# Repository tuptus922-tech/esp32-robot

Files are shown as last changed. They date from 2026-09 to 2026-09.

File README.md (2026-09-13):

# 🤖 ESP32 Robot Desk Pet — Kompletny Przewodnik

Interaktywny miniaturowy robot biurkowy (**Desk Companion Pet**) oparty na mikrokontrolerze **ESP32**, wyświetlaczu OLED 0.96", akcelerometrze/żyroskopie **MPU-6050**, podwójnym pojemnościowym czujniku głaskania oraz pasywnym buzzerze piezo.

Dzięki **modułowej architekturze Core-and-Armor** całą elektronikę montujesz i podłączasz **tylko jeden raz** w centralnym stelażu, a wygląd zewnętrzny robota możesz zmieniać w sekundę, nasuwając wybraną obudowę (**Cyber-Titan Apex**, **Mecha-Kawaii**, **Retro CRT** lub **Steam-Titan Nautilus**) bez rozkręcania śrub i bez dotykania kabli!

---

## ⚡ Spis Treści
1. [KROK 1: Flashowanie ESP32 (Wgrywanie programu)](#-krok-1-flashowanie-esp32-wgrywanie-programu)
2. [KROK 2: Druk 3D — Dokładna lista plików STL (4 style)](#-krok-2-druk-3d--dokładna-lista-plików-stl)
3. [KROK 3: Schemat połączeń przewodów (Hardware Pinout)](#-krok-3-schemat-połączeń-przewodów-hardware-pinout)
4. [KROK 4: Montaż elektroniki w stelażu (Złóż raz i zapomnij!)](#-krok-4-montaż-elektroniki-w-stelażu-złóż-raz-i-zapomnij)
5. [KROK 5: Błyskawiczna wymiana obudów (Quick-Swap Slide-On)](#-krok-5-błyskawiczna-wymiana-obudów-quick-swap-slide-on)
6. [✨ Funkcje, animacje i sterowanie](#-funkcje-animacje-i-sterowanie)
7. [📦 Lista zakupowa części (BOM)](#-lista-zakupowa-części-bom)

---

## ⚡ KROK 1: Flashowanie ESP32 (Wgrywanie programu)

Kod robota znajduje się w pliku [`src/main.cpp`](src/main.cpp), a konfiguracja projektu, parametry mikrokontrolera i biblioteki są zdefiniowane w [`platformio.ini`](platformio.ini).

### Wymagania:
* Płytka **ESP32 DevKit V1** (30-pin, polecane z gniazdem USB-C lub microUSB).
* Kabel USB **do transmisji danych** (nie tylko do ładowania!).
* Komputer z Windows, macOS lub Linux.

---

### Metoda A: Przez VS Code + PlatformIO IDE (Najprostsza — Zalecana)

1. **Pobierz i zainstaluj edytor [VS Code (Visual Studio Code)](https://code.visualstudio.com/)**.
2. W VS Code przejdź do zakładki rozszerzeń (`Ctrl + Shift + X`), wyszukaj **PlatformIO IDE** i kliknij **Install**.
3. Kliknij `File -> Open Folder...` i wskaż sklonowany folder projektu:
   ```bash
   esp32-robot
   ```
4. Podłącz płytkę ESP32 kablem USB do portu komputera.
5. Na dolnym niebieskim pasku VS Code pojawią się ikonki PlatformIO:
   * **`✓` (Build)**: kompilacja programu.
   * **`→` (Upload)**: automatyczna kompilacja i wgranie programu do pamięci ESP32!
   * **`🔌` (Serial Monitor)**: podgląd logów diagnostycznych (115200 baud).
6. Kliknij **`→` (Upload)**. PlatformIO samoczynnie pobierze wymagane biblioteki (Adafruit SSD1306, GFX, MPU6050, BusIO), skompiluje kod i wgra go na Twoją płytkę.
7. Po wgraniu robot wyda powitalny dźwięk i otworzy animowane oczy na ekranie!

---

### Metoda B: Przez Terminal (CLI)

Jeśli wolisz terminal, wystarczy wpisać:

```bash
# 1. Przejdź do katalogu projektu
cd esp32-robot

# 2. Skompiluj i wgraj program na podłączone ESP32
pio run -t upload

# 3. Otwórz monitor portu szeregowego
pio device monitor -b 115200
```
*(Jeśli komenda `pio` nie jest w ścieżce PATH, użyj pełnej ścieżki: `~/.platformio/penv/bin/pio run -t upload`)*

---

### ❓ Rozwiązywanie problemów z wgrywaniem:

* **Błąd `Connecting........_____.....`**:  
  Niektóre płytki ESP32 wymagają ręcznego wejścia w tryb bootloadera. Gdy na ekranie pojawi się napis `Connecting...`, **naciśnij i przytrzymaj przez 2 sekundy przycisk BOOT** na płytce ESP32, po czym puść.
* **Komputer nie widzi portu COM / `/dev/ttyUSB0`**:  
  Zainstaluj uniwersalne sterowniki układu USB-UART dla ESP32: **CP2102** (Silicon Labs) lub **CH340**.
* **Chcesz przetestować kod bez fizycznej płytki?**  
  Projekt zawiera plik [`diagram.json`](diagram.json) — możesz uruchomić pełną symulację robota w wirtualnym środowisku **Wokwi** w przeglądarce!

---

## 🖨️ KROK 2: Druk 3D — Dokładna lista plików STL

Projekt wykorzystuje modułowy system **Core-and-Armor**:
1. **Drukujesz ZAWSZE 1x Stelaż Centralny (Universal Core Chassis v2.0 - Pro Precision Edition)** — to w nim na stałe mieszka cała elektronika w dedykowanych gniazdach pod dokładne wymiary fabryczne podzespołów.
2. **Wybierasz 1 z 4 obudów zewnętrznych (Głowa + Klawisze)** — nasuwasz ją od góry na stelaż (**Quick-Swap Slide-On**)!

---

### 🧩 CZĘŚĆ 1: Centralny Stelaż (Drukujesz ZAWSZE, 1 raz dla każdego robota)

| Plik STL | Ilość | Ścieżka do pliku | Dedykowane gniazda i wymiary |
| :--- | :---: | :--- | :--- |
| **`core_chassis.stl`** | **1 szt.** | [`cad_models/stl_print/core_chassis.stl`](cad_models/stl_print/core_chassis.stl) | **Stelaż v2.0 z dedykowanymi gniazdami:**<br>• **ESP32 DevKit V1**: gniazdo 51.8x28.7mm z 2 głębokimi kanałami na 2x15 pinów goldpin + tunel kablowy<br>• **OLED 0.96" I2C**: kieszeń 27.4x27.4mm, standardowe otwory M2 w rozstawie **23.5x23.5mm**, kąt 80° z kratownicą<br>• **MPU-6050 (GY-521)**: kieszeń 21.2x16.0mm, 2x otwory M2.5 (rozstaw 15.2mm) i okno na piny<br>• **Buzzer 12mm**: kubek akustyczny fi 12.4x9.5mm z 2 otworami na piny (rozstaw 7.6mm)<br>• **3x Switche 6x6mm**: 3 kieszenie 6.5x6.5x4.2mm z przepustami na nóżki |

---

### 🎭 CZĘŚĆ 2: Wybierz 1 z 3 Obudów Zewnętrznych (Nasuwasz na stelaż)

#### 🛡️ Opcja A: Cyber-Titan Apex (Ciężki Mech Bojowy 72mm z wyrzutniami, rogami i dyszami)
*Klimat: Armored Core / Gundam Heavy Assault. Agresywna sylwetka V-Taper, potężne naramienniki 72mm z wyrzutniami rakiet, 68mm rogi bojowe V-Fin, kły mandibles i podwójne dysze dopalaczy.*

| Plik STL | Ilość | Ścieżka do pliku | Zalecany kolor filamentu |
| :--- | :---: | :--- | :--- |
| **`dreadnought_glowa.stl`** | **1 szt.** | [`cad_models/stl_print/dreadnought/dreadnought_glowa.stl`](cad_models/stl_print/dreadnought/dreadnought_glowa.stl) | Matowy grafit / Carbon Black |
| **`dreadnought_przycisk_romb.stl`** | **1 szt.** | [`cad_models/stl_print/dreadnought/dreadnought_przycisk_romb.stl`](cad_models/stl_print/dreadnought/dreadnought_przycisk_romb.stl) | Złoty metalik lub Cyber Pomarańcz |
| **`dreadnought_przycisk_strzalka_l.stl`** | **1 szt.** | [`cad_models/stl_print/dreadnought/dreadnought_przycisk_strzalka_l.stl`](cad_models/stl_print/dreadnought/dreadnought_przycisk_strzalka_l.stl) | Tytanowy szary / Ciemny grafit |
| **`dreadnought_przycisk_strzalka_p.stl`** | **1 szt.** | [`cad_models/stl_print/dreadnought/dreadnought_przycisk_strzalka_p.stl`](cad_models/stl_print/dreadnought/dreadnought_przycisk_strzalka_p.stl) | Tytanowy szary / Ciemny grafit |
| *`dreadnought_podstawa.stl`* | *(opcjonalnie)* | [`cad_models/stl_print/dreadnought/dreadnought_podstawa.stl`](cad_models/stl_print/dreadnought/dreadnought_podstawa.stl) | *Opcjonalna baza ze stopami czołgowymi* |

---

#### 🌸 Opcja B: Cyber-Capsule Mecha-Kawaii (Anime Kotek Neko ze szponterami)
*Klimat: Cyberpunk Anime Companion. Przestrzenny wizjer 3D, kocie uszka, nauszniki Audio-Pod, 4 boczne żebra pancerza ("szpontery"), wąsy i przyciski z serduszkiem oraz łapkami.*

| Plik STL | Ilość | Ścieżka do pliku | Zalecany kolor filamentu |
| :--- | :---: | :--- | :--- |
| **`mecha_kawaii_glowa.stl`** | **1 szt.** | [`cad_models/stl_print/mecha_kawaii/mecha_kawaii_glowa.stl`](cad_models/stl_print/mecha_kawaii/mecha_kawaii_glowa.stl) | Pastel Sakura Pink / Perłowa biel |
| **`mecha_kawaii_przycisk_serce.stl`** | **1 szt.** | [`cad_models/stl_print/mecha_kawaii/mecha_kawaii_przycisk_serce.stl`](cad_models/stl_print/mecha_kawaii/mecha_kawaii_przycisk_serce.stl) | Neon Fuksja / Czerwony |
| **`mecha_kawaii_przycisk_lapka.stl`** | **2 szt.** | [`cad_models/stl_print/mecha_kawaii/mecha_kawaii_przycisk_lapka.stl`](cad_models/stl_print/mecha_kawaii/mecha_kawaii_przycisk_lapka.stl) | Śmietankowa biel |
| *`mecha_kawaii_podstawa.stl`* | *(opcjonalnie)* | [`cad_models/stl_print/mecha_kawaii/mecha_kawaii_podstawa.stl`](cad_models/stl_print/mecha_kawaii/mecha_kawaii_podstawa.stl) | *Opcjonalna baza z przednimi łapkami* |

---

#### 📺 Opcja C: Retro CRT Minimalist (Klasyczny Komputer Biurkowy Vintage)
*Klimat: Macintosh 1984 / Dieter Rams Braun. Minimalistyczna bryła o miękkich krawędziach R4, zlicowane okno ekranu i ergonomiczne kopułki przycisków.*

| Plik STL | Ilość | Ścieżka do pliku | Zalecany kolor filamentu |
| :--- | :---: | :--- | :--- |
| **`obudowa_gora_glowa.stl`** | **1 szt.** | [`cad_models/stl_print/obudowa_gora_glowa.stl`](cad_models/stl_print/obudowa_gora_glowa.stl) | Kość słoniowa / Vintage Grey |
| **`przycisk_nakladka.stl`** | **3 szt.** | [`cad_models/stl_print/przycisk_nakladka.stl`](cad_models/stl_print/przycisk_nakladka.stl) | Turkusowy Cyan / Żółty akcent retro |
| *`obudowa_dol_podstawa.stl`* | *(opcjonalnie)* | [`cad_models/stl_print/obudowa_dol_podstawa.stl`](cad_models/stl_print/obudowa_dol_podstawa.stl) | *Opcjonalna klasyczna baza* |

---

#### ⚙️ Opcja D: Steam-Titan Nautilus ULTRA (Industrial Steampunk / Ciężki Parowy Kocioł Bojowy)
*Klimat: Heavy Victorian Industrial / BioShock Nautilus. Zaokrąglona czasza kotła parowego, potrójna klatka ochronna iluminatora (roll-cage), podwójne wiktoriańskie kominy z potrójnymi kryzami chłodzącymi, boczne manometry ciśnienia pary ze wskazówkami w czerwonej strefie, odsłonięte koła zębate napędowe po bokach, okrętowe mosiężne iluminatory, pancerne żaluzje wentylacyjne, zawory bezpieczeństwa na dachu, wieżyczka peryskopowa, 29 trójwymiarowych nitów kotłowych, śruby sześciokątne oraz mosiężne 6-ramienne koło zaworowe jako przycisk.*

| Plik STL | Ilość | Ścieżka do pliku | Zalecany kolor filamentu |
| :--- | :---: | :--- | :--- |
| **`dieselpunk_glowa.stl`** | **1 szt.** | [`cad_models/stl_print/dieselpunk/dieselpunk_glowa.stl`](cad_models/stl_print/dieselpunk/dieselpunk_glowa.stl) | Stal kotłowa / Ciemny grafit / Mosiądz Silk |
| **`dieselpunk_przycisk_zawor.stl`** | **1 szt.** | [`cad_models/stl_print/dieselpunk/dieselpunk_przycisk_zawor.stl`](cad_models/stl_print/dieselpunk/dieselpunk_przycisk_zawor.stl) | Złoty Mosiądz / Polerowany brąz |
| **`dieselpunk_przycisk_ryfel_l.stl`** | **1 szt.** | [`cad_models/stl_print/dieselpunk/dieselpunk_przycisk_ryfel_l.stl`](cad_models/stl_print/dieselpunk/dieselpunk_przycisk_ryfel_l.stl) | Oksydowana stal / Gunmetal |
| **`dieselpunk_przycisk_ryfel_p.stl`** | **1 szt.** | [`cad_models/stl_print/dieselpunk/dieselpunk_przycisk_ryfel_p.stl`](cad_models/stl_print/dieselpunk/dieselpunk_przycisk_ryfel_p.stl) | Oksydowana stal / Gunmetal |
| *`dieselpunk_podstawa.stl`* | *(opcjonalnie)* | [`cad_models/stl_print/dieselpunk/dieselpunk_podstawa.stl`](cad_models/stl_print/dieselpunk/dieselpunk_podstawa.stl) | *Opcjonalna baza kotła ze stopami śrubowymi* |

---

### ⚙️ Rekomendowane Ustawienia Slicera (Bambu Studio / OrcaSlicer / PrusaSlicer / Cura):

* **Materiał**: PLA lub PETG.
* **Wysokość warstwy (Layer height)**:
  * Stelaż i obudowy główne: `0.20 mm`
  * Przyciski: `0.16 mm` (zapewnia idealną gładkość ikonek i kołnierzy).
* **Ścianki / Obrysy (Walls / Perimeters)**: `3 lub 4` (min. 1.2 – 1.6 mm grubości).
* **Wypełnienie (Infill)**: `15% – 20%` (Zalecany wzór: **Gyroid**).
* **Podpory (Supports)**: **WYŁĄCZONE (Supports: OFF / None)**.  
  *Wszystkie skosy, daszki, wyrzutnie rakiet i rogi zaprojektowano pod kątem $\le 45^\circ$, co gwarantuje czysty, idealny wydruk bez jakichkolwiek podpór!*

---

## 📌 KROK 3: Schemat połączeń przewodów (Hardware Pinout)

Podłącz komponenty do odpowiednich pinów ESP32:

| Urządzenie | Wyprowadzenie (Pin) | Pin ESP32 | Funkcja i opis |
| :--- | :--- | :--- | :--- |
| **Wyświetlacz OLED 0.96"** | **SDA** | **GPIO 21** | Szyna danych I2C |
| (SSD1306 128x64) | **SCL** | **GPIO 22** | Szyna zegara I2C |
| | **VCC** | **3.3V** | Zasilanie logiczne ekranu |
| | **GND** | **GND** | Wspólna masa |
| **Czujnik MPU-6050** | **SDA** | **GPIO 21** | Wspólna linia danych magistrali I2C |
| (Żyroskop / Akcelerometr) | **SCL** | **GPIO 22** | Wspólna linia zegara magistrali I2C |
| | **VCC** | **3.3V** lub **5V** | Zasilanie czujnika ruchu |
| | **GND** | **GND** | Wspólna masa |
| **Buzzer Pasywny 12mm** | **+ (Sygnał)** | **GPIO 25** | Generowanie tonów PWM |
| | **-** | **GND** | Wspólna masa |
| **Przycisk LEWY** | Pin 1 | **GPIO 18** | Drugi pin przycisku do **GND** (wbudowany PULLUP) |
| **Przycisk ŚRODEK (OK)** | Pin 1 | **GPIO 19** | Drugi pin przycisku do **GND** (wbudowany PULLUP) |
| **Przycisk PRAWY** | Pin 1 | **GPIO 23** | Drugi pin przycisku do **GND** (wbudowany PULLUP) |
| **Strefa dotyku PRZÓD** | Pasek folii A | **GPIO 32** (T9) | Dotyk pojemnościowy (1 kabelek do folii) |
| **Strefa dotyku TYŁ** | Pasek folii B | **GPIO 33** (T8) | Dotyk pojemnościowy (1 kabelek do folii) |

> [!TIP]
> **Jak wykonać strefy głaskania z folii aluminiowej?**
> 1. Wytnij dwa paski zwykłej kuchennej folii aluminiowej o wymiarach ok. **15 mm x 30 mm**.
> 2. Przyklej taśmą lub przylutuj po jednym kabelku: jeden do pinu **GPIO 32**, drugi do **GPIO 33**.
> 3. Paski umieść pod dachem obudowy (jeden z przodu na czole, drugi z tyłu głowy).
> 4. Przy każdym uruchomieniu ESP32 samoczynnie kalibruje czułość do Twojej dłoni i grubości plastiku!

---

## 🛠️ KROK 4: Montaż elektroniki w stelażu (Złóż raz i zapomnij!)

Całą elektronikę osadzasz trwale w wydrukowanym stelażu [`core_chassis.stl`](cad_models/stl_print/core_chassis.stl):

1. **Przyciski**: Wsuń 3 mikroprzełączniki Tact Switch 6x6 mm w przednie gniazda stelaża. Opierają się o solidną tylną ścianę, dzięki czemu nie uginają się przy klikaniu.
2. **ESP32**: Wsuń płytkę ESP32 DevKit V1 w szyny prowadzące stelaża od góry, aż kliknie w zatrzaski krawędziowe. Port USB idealnie zgra się z tylnym oknem.
3. **MPU-6050**: Połóż czujnik poziomo w dedykowanej niecce między szynami.
4. **OLED 0.96"**: Wsuń wyświetlacz w ramkę masztu nachylonego pod fabrycznym kątem **80°**. Cztery kołki centrujące zablokują ekran w osi okna.
5. **Buzzer 12mm**: Wciśnij przetwornik w cylindryczny koszyk na szczycie wieży (press-fit na klik). Dźwięk skierowany jest wprost do góry.
6. **Nóżki**: Wklej 4 silikonowe nóżki antypoślizgowe (fi 8 mm) w gniazda na spodzie stelaża.

Stelaż z podłączonym kablem USB stoi teraz stabilnie na Twoim biurku!

---

## 🎭 KROK 5: Błyskawiczna wymiana obudów (Quick-Swap Slide-On)

| 🧩 1. Stelaż Core | 🛡️ 2. Titan Apex | 🌸 3. Neko Kawaii | ⚙️ 4. Steam Nautilus |
| :---: | :---: | :---: | :---: |
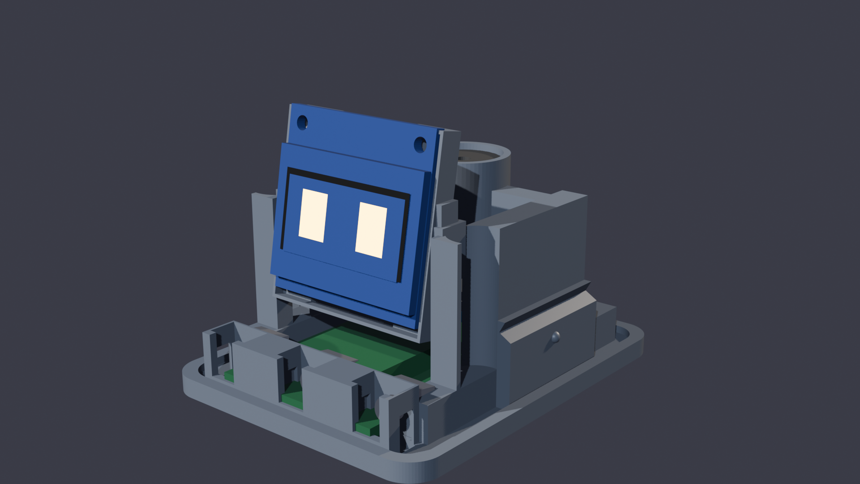
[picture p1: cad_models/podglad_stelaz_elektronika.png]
Stelaż Core
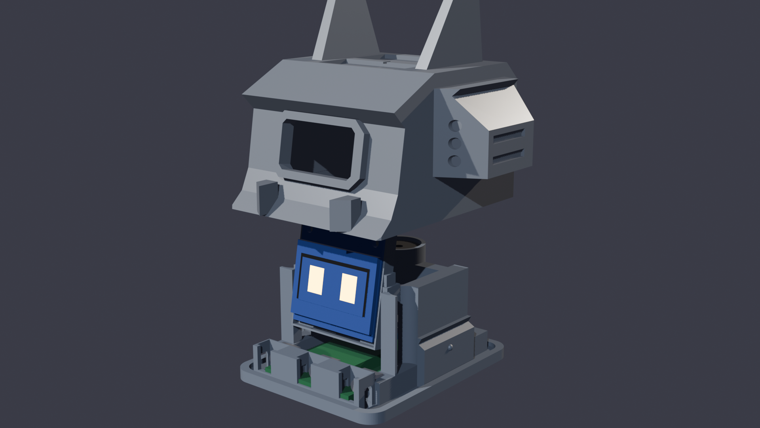
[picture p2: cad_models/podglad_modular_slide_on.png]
Nasuwanie Apex
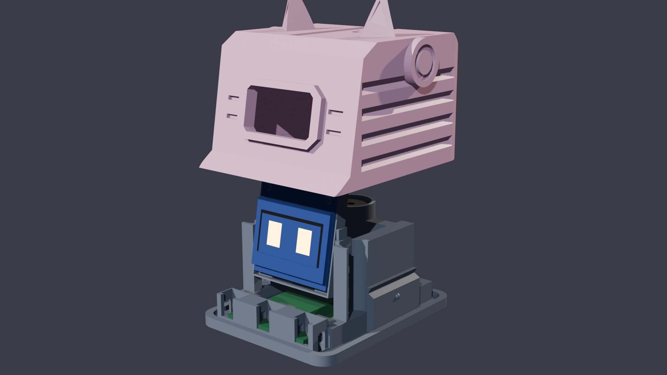
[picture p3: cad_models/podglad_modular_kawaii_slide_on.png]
Nasuwanie Kawaii
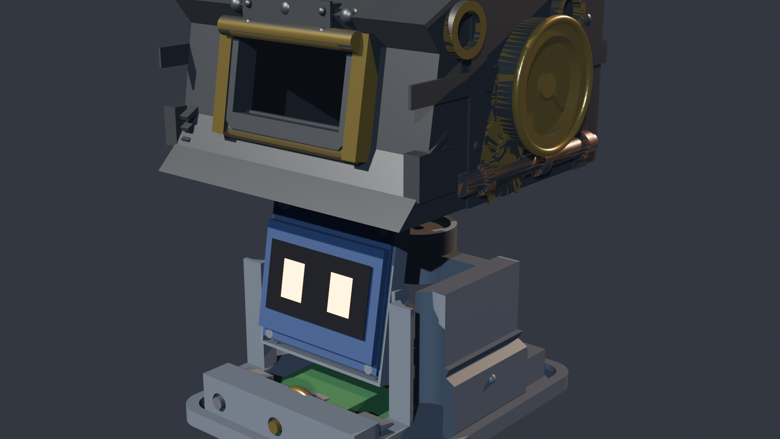
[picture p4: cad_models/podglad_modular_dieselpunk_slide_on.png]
Nasuwanie Nautilus
|  |  |  |  |

1. Weź wybraną obudowę (np. **Cyber-Titan Apex**, **Mecha-Kawaii** lub **Steam-Titan Nautilus**).
2. Wsuń od środka w jej przednie otwory dedykowane nakładki przycisków (kołnierz zabezpiecza je przed wypadnięciem).
3. **Nasuń obudowę od góry na stelaż**: wewnętrzne szyny prowadzące gładko poprowadzą obudowę w dół, a dolne zatrzaski kulkowe klikną na dole.
4. **Chcesz zmienić robota w kotka, mecha bojowego lub parowy kocioł?**  
   Po prostu chwyć obudowę, pociągnij w górę i załóż inną! Zero śrubokrętów, zero odpinania kabli!

---

## ✨ Funkcje, animacje i sterowanie

* 👀 **Żywe, animowane oczy OLED**: Płynne mruganie, naturalne zerkanie na boki, 5 stylów oczu (*Standard, Cat Eyes, Cyber, Hearts, Anime*) oraz 4 motywy graficzne.
* 🥰 **Wykrywanie gestu głaskania (Petting)**: Przejechanie dłonią od czoła do tyłu głowy wyzwala wieloetapową animację zadowolenia (bijące serca, rumieńce, uroczy pyszczek `ω`, mruczenie kota). Głaskanie pod włos wywołuje zdziwienie z pytajnikiem `?`.
* 📳 **Czujnik ruchu**: Robot zasypia po bezczynności i budzi się po podniesieniu lub potrząśnięciu.
* 📋 **Menu Kafelkowe**:
  1. *Eye Style* (wybór oczu i motywu graficznego)
  2. *Pomodoro* (stoper pracy 25 min)
  3. *Dino Jump* (gra zręcznościowa na ekranie)
  4. *Exit* (powrót do trybu zwierzaka)
* 💻 **Diagnostyka przez Serial Monitor (115200 baud)**:
  Wpisz w konsoli: `touch` (odczyt czułości), `calib` (autokalibracja dotyku), `pet` (test głaskania), `shake` (test ruchu).

---

## 🎨 Gotowe Projekty 3D i Blender

Wszystkie pliki źródłowe znajdziesz w katalogu [`cad_models/`](cad_models/):
* ⚙️ **Projekt Blendera Steam-Titan Nautilus:** [`cad_models/robot_dieselpunk.blend`](cad_models/robot_dieselpunk.blend)
* 🛡️ **Projekt Blendera Cyber-Titan Apex:** [`cad_models/robot_dreadnought.blend`](cad_models/robot_dreadnought.blend)
* 🌸 **Projekt Blendera Mecha-Kawaii:** [`cad_models/robot_mecha_kawaii.blend`](cad_models/robot_mecha_kawaii.blend)
* 📺 **Projekt Blendera Retro CRT:** [`cad_models/robot_obudowa_klasyczna.blend`](cad_models/robot_obudowa_klasyczna.blend)
* 🧩 **Projekt Blendera Stelaża i Slide-On:** [`cad_models/robot_modular_core.blend`](cad_models/robot_modular_core.blend)
* 📐 **Parametryczne modele FreeCAD i pliki STEP:** [`cad_models/robot_dieselpunk_3d.FCStd`](cad_models/robot_dieselpunk_3d.FCStd), [`cad_models/core_chassis.step`](cad_models/core_chassis.step), [`cad_models/robot_core_chassis.FCStd`](cad_models/robot_core_chassis.FCStd)

---

## 📦 Lista zakupowa części (BOM)

1. **1x ESP32 DevKit V1** (30-pin, CP2102 lub CH340).
2. **1x Wyświetlacz OLED 0.96" I2C SSD1306** (128x64, kolor biały lub niebieski).
3. **1x Moduł MPU-6050** (GY-521, 3-osiowy akcelerometr + żyroskop).
4. **1x Buzzer Pasywny Piezo 12mm** (Passive Piezo Buzzer 5V/3.3V).
5. **3x Mikroprzełączniki Tact Switch 6x6 mm** (wysokość trzpienia 4.3 mm – 7 mm).
6. **Przewody Dupont żeńsko-żeńskie** (10-15 cm) + kawałek folii aluminiowej kuchennej.
7. **4x Samoprzylepne nóżki silikonowe fi 8 mm** (na spód stelaża).

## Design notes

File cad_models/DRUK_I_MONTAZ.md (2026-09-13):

# 🖨️ Przewodnik Druku 3D i Montażu Obudowy Robota ESP32 Pet

Kompleksowa instrukcja przygotowania plików, ustawień slicera oraz montażu trzech unikalnych obudów biurkowych dla robota companion pet.

---

## 🎭 Cztery Unikalne Wersje Obudowy do Wyboru

Możesz wybrać jedną z czterech kompletnych, w 100% kompatybilnych z tą samą elektroniką obudów:

| Cecha | Wersja 1: Retro CRT Minimalist | Wersja 2: Cyber-Capsule Mecha-Kawaii | Wersja 3: Cyber-Titan Apex (Mecha) | Wersja 4: Steam-Titan Nautilus (Dieselpunk) |
| :--- | :--- | :--- | :--- | :--- |
| **Klimat / Styl** | Klasyczny retro komputer biurkowy | Cyberpunk / Anime Mecha Neko | Ciężki szturmowy mech bojowy / Gundam | Industrial Steampunk / BioShock Nautilus |
| **Sylwetka / Wymiary** | 50 x 50 x 48 mm, zaokrąglony prostopadłościan | 50 x 50 x 56 mm, kapsuła z uszkami | **72 mm szerokości**, **68 mm wysokości** | **54 mm kocioł ciśnieniowy**, podwójne kominy 58 mm |
| **Boki obudowy** | Gładkie zaokrąglenia R4 | 4 głębokie żebra ("szpontery") + Audio-Pod | Naramienniki 72mm z wyrzutniami rakiet | **Wielkie manometry parowe (fi 21mm)** + rurociągi miedziane |
| **Ekran OLED** | Zlicowane okno | Oktagonalny wizjer 3D + wąsy mecha | Pancerny kokpit, blast-shield 45° i kły | **Potrójna klatka ochronna iluminatora (roll-cage)** |
| **Głowa / Dach** | Płaski dach | Fasetowane uszka + kocia łapka | Rogi bojowe V-Fin 68mm | **Podwójne wiktoriańskie kominy z kryzami i radiatorami** |
| **Napęd / Tył** | Płaski tył | Płaski tył | Podwójne dysze odrzutowe dopalaczy | Półkolisty zbiornik z kołem ryglowym włazu inspekcyjnego |
| **Podstawa** | Standardowa niska baza | Baza z przednimi łapkami i pazurkami | Ciężkie gąsienice pancerne crawler 63mm | Baza kotła z 4 kołnierzami śrubowymi i żaluzją |
| **Przyciski** | 3 gładkie kopułki | Środek: Serduszko ❤️, Boki: Łapki 🐾 | Środek: Diament `◆`, Boki: Strzałki `◀` `▶` | Środek: Koło zaworu parowego, Boki: Płyty ryflowane |
| **Katalog STL** | `cad_models/stl_print/` | `cad_models/stl_print/mecha_kawaii/` | `cad_models/stl_print/dreadnought/` | `cad_models/stl_print/dieselpunk/` |
| **Plik Blender** | `robot_obudowa_klasyczna.blend` | `robot_mecha_kawaii.blend` | `robot_dreadnought.blend` | `robot_dieselpunk.blend` |

---

## 📂 Pliki STL do Druku

Wszystkie modele zostały zaprojektowane w pełnej zgodności z zasadami **Design for Additive Manufacturing (DFAM)**, są bryłami zamkniętymi (watertight/manifold) i posiadają zoptymalizowane tolerancje pasowania (0.25–0.35 mm).

---

### 🧩 UNIWERSALNY STELAŻ ELEKTRONIKI v2.2 (Free Rail Edition)
Plik: [`cad_models/stl_print/core_chassis.stl`](file:///home/tuptus/Dokumenty/PlatformIO/Projects/robot/cad_models/stl_print/core_chassis.stl)

| Plik STL | Ilość | Opis / Rola w konstrukcji | Orientacja na stole |
| :--- | :---: | :--- | :--- |
| [`core_chassis.stl`](file:///home/tuptus/Dokumenty/PlatformIO/Projects/robot/cad_models/stl_print/core_chassis.stl) | **1 szt.** | **Centralny stelaż nośny v2.3 (Free Rail & Reinforced OLED Edition)**: W 100% odsłonięta, całkowicie drożna szyna montażowa ESP32 DevKit V1 (szerokość 29.2mm) z 2 głębokimi kanałami na piny goldpin (4.1x4.7mm) i tunelem kablowym; boczne pylony nośne umieszczone poza obrysem płytki (X = ±15.0..19.5mm); mostek MPU-6050 wyniesiony na Z=12.0mm ponad ESP32 z otworami M2.5 (rozstaw 15.2mm); wzmocniony maszt OLED 80° z ramką 27.6x27.6mm, 4 otworami gwintowanymi M2 (23.5x23.5mm), oknem SMD (20x16mm), slotem I2C (14x5.5mm) i szczeliną na taśmę FPC (16x2.5mm); podwójne zastrzały kratownicowe (truss); wiszący kubek buzzera fi 12.4x9.0mm podparty z pylonów bocznych; 3 kieszenie 7.2x4.5x6.8mm na switche 6x6mm ze zderzakiem ESP32 na Y=-26.0mm; szyny Quick-Swap z zatrzaskami kulkowymi | Płasko na spodzie (Z=0, 0 podpór) |

> [!IMPORTANT]
> **Dlaczego stelaż v2.3 to rewolucja?**  
> Całkowicie wyeliminowano problem blokowania szyn przez pylony czy podpory oraz ułamujących się bolców OLED. W nowym stelażu **Universal Core Chassis v2.3**:
> - **ESP32 DevKit V1**: Szyna ma pełne 29.2 mm szerokości (tolerancja na druk FDM) i jest **w 100% otwarta od góry i od tyłu**. Płytka wsuwa się gładko w prowadnice aż do przedniego zderzaka (Y=-26.0mm) i zatrzaskuje w bocznych wypustkach sprężystych na Z=7.1mm.
> - **Głębokie kanały na piny goldpin**: Dwa kanały o szerokości 4.1 mm i głębokości 4.7 mm (od Z=5.5 do Z=0.8 mm) zapewniają, że dolne piny 2x15 goldpin wiszą swobodnie w powietrzu i nie dotykają dna!
> - **Pylony nośne poza obrysem ESP32**: Kolumny konstrukcyjne stelaża zostały odsunięte na zewnątrz (X = ±15.0 do ±19.5 mm) – zero słupków stojących na pinach czy laminacie ESP32 (0.0000 mm³ kolizji)!
> - **Mostek MPU-6050 (GY-521)**: Wyniesiony na Z = 12.0 mm ponad ESP32 (6.5 mm prześwitu nad płytką bazową). Płytka czujnika spoczywa stabilnie na konsoli z otworami M2.5 (rozstaw 15.2 mm) i przednim oknem kablowym na magistralę I2C.
> - **Komora akustyczna Buzzera 12mm**: Kubek rezonansowy fi 12.4 mm wisi na Z = 23.0 mm podparty poprzecznymi ramionami z bocznych pylonów. Zero kolizji z MPU i ESP32.
> - **Wzmocniony Maszt OLED 0.96" SSD1306 (v2.3)**: 
>   - Gruba kieszeń nośna 3.8 mm (dla stabilności gwintów),
>   - 4 otwory pilotowe pod wkręty M2 (fi 1.8 mm x 4.5 mm) w rozstawie 23.5 x 23.5 mm (zamiast łamliwych plastikowych bolców),
>   - Tylne okno odciążające SMD (20.0 x 16.0 mm),
>   - Dolne wycięcie ochronne na taśmę giętką FPC (16.0 x 2.5 mm),
>   - Górny szeroki przepust kątowy na wtyk/złącze 4-pin I2C (14.0 x 5.5 mm),
>   - Podwójne zastrzały kratownicowe (truss) po bokach — maszt jest sztywny jak skała!
> - **Zarządzanie kablami**: Centralny kanał kablowy pod ESP32 pozwala schować wszystkie przewody połączeniowe. Zero wiszących kabli!
> Montujesz i lutujesz całą elektronikę **tylko raz na stelażu**! Każda z czterech obudów górnych (Classic CRT, Mecha-Kawaii, Cyber-Titan Apex, Steam-Titan Nautilus ULTRA) nasuwa się na stelaż od góry wzdłuż szyn Quick-Swap i zatrzaskuje na kulkach detent. Aby zmienić wygląd robota, po prostu pociągasz głowę w górę i zakładasz nową – bez śrub, bez rozłączania kabli i bez kleju!

---

### 🛡️ Wersja 3: Cyber-Titan Apex (Katalog `cad_models/stl_print/dreadnought/`)

| Plik STL | Ilość | Opis / Rola w konstrukcji | Orientacja na stole |
| :--- | :---: | :--- | :--- |
| [`dreadnought_podstawa.stl`](file:///home/tuptus/Dokumenty/PlatformIO/Projects/robot/cad_models/stl_print/dreadnought/dreadnought_podstawa.stl) | 1 szt. | Dolne chassis o rozpiętości 63mm z segmentami gąsienic czołgowych, szynami ESP32 i portem USB | Płasko na spodzie (Z=0) |
| [`dreadnought_glowa.stl`](file:///home/tuptus/Dokumenty/PlatformIO/Projects/robot/cad_models/stl_print/dreadnought/dreadnought_glowa.stl) | 1 szt. | Głowa Apex: 72mm naramienniki z wyrzutniami, 68mm rogi V-Fin, daszek blast-shield, kły mandibles i dysze odrzutowe | Płasko dolnym kołnierzem do stołu |
| [`dreadnought_przycisk_romb.stl`](file:///home/tuptus/Dokumenty/PlatformIO/Projects/robot/cad_models/stl_print/dreadnought/dreadnought_przycisk_romb.stl) | 1 szt. | Środkowy przycisk reaktora rdzenia (OK) z fasetowanym diamentem `◆` | Płasko kołnierzem do stołu |
| [`dreadnought_przycisk_strzalka_l.stl`](file:///home/tuptus/Dokumenty/PlatformIO/Projects/robot/cad_models/stl_print/dreadnought/dreadnought_przycisk_strzalka_l.stl) | 1 szt. | Lewy przycisk nawigacyjny ze strzałką bojową `◀` | Płasko kołnierzem do stołu |
| [`dreadnought_przycisk_strzalka_p.stl`](file:///home/tuptus/Dokumenty/PlatformIO/Projects/robot/cad_models/stl_print/dreadnought/dreadnought_przycisk_strzalka_p.stl) | 1 szt. | Prawy przycisk nawigacyjny ze strzałką bojową `▶` | Płasko kołnierzem do stołu |
| [`dreadnought_robot_kompletny.stl`](file:///home/tuptus/Dokumenty/PlatformIO/Projects/robot/cad_models/stl_print/dreadnought/dreadnought_robot_kompletny.stl) | - | Pełne złożenie modelu Cyber-Titan Apex (do podglądu w slicerze) | - |

---

### 🌸 Wersja 2: Cyber-Capsule Mecha-Kawaii (Katalog `cad_models/stl_print/mecha_kawaii/`)

| Plik STL | Ilość | Opis / Rola w konstrukcji | Orientacja na stole |
| :--- | :---: | :--- | :--- |
| [`mecha_kawaii_podstawa.stl`](file:///home/tuptus/Dokumenty/PlatformIO/Projects/robot/cad_models/stl_print/mecha_kawaii/mecha_kawaii_podstawa.stl) | 1 szt. | Dolne chassis z szynami ESP32, wycięciem USB i przednimi łapkami mecha | Płasko na spodzie (Z=0) |
| [`mecha_kawaii_glowa.stl`](file:///home/tuptus/Dokumenty/PlatformIO/Projects/robot/cad_models/stl_print/mecha_kawaii/mecha_kawaii_glowa.stl) | 1 szt. | Głowa ze szponterami, wizjerem 3D, uszkami, nausznikami i torem głaskania | Płasko dolnym kołnierzem do stołu |
| [`mecha_kawaii_przycisk_serce.stl`](file:///home/tuptus/Dokumenty/PlatformIO/Projects/robot/cad_models/stl_print/mecha_kawaii/mecha_kawaii_przycisk_serce.stl) | 1 szt. | Środkowy przycisk nawigacyjny (OK) z wytłoczonym serduszkiem | Płasko kołnierzem do stołu |
| [`mecha_kawaii_przycisk_lapka.stl`](file:///home/tuptus/Dokumenty/PlatformIO/Projects/robot/cad_models/stl_print/mecha_kawaii/mecha_kawaii_przycisk_lapka.stl) | **2 szt.** | Boczne przyciski (Lewo / Prawo) z wytłoczoną kocią łapką | Płasko kołnierzem do stołu |
| [`mecha_kawaii_robot_kompletny.stl`](file:///home/tuptus/Dokumenty/PlatformIO/Projects/robot/cad_models/stl_print/mecha_kawaii/mecha_kawaii_robot_kompletny.stl) | - | Pełne złożenie modelu (do podglądu w slicerze) | - |

---

### 📺 Wersja 1: Retro CRT Minimalist (Katalog `cad_models/stl_print/`)

| Plik STL | Ilość | Opis / Rola w konstrukcji | Orientacja na stole |
| :--- | :---: | :--- | :--- |
| [`obudowa_dol_podstawa.stl`](file:///home/tuptus/Dokumenty/PlatformIO/Projects/robot/cad_models/stl_print/obudowa_dol_podstawa.stl) | 1 szt. | Dolne chassis z szynami ESP32, wycięciem USB i gniazdami śrub M3 | Płasko na spodzie (Z=0) |
| [`obudowa_gora_glowa.stl`](file:///home/tuptus/Dokumenty/PlatformIO/Projects/robot/cad_models/stl_print/obudowa_gora_glowa.stl) | 1 szt. | Korpus: okno OLED 0.96", kieszenie dotyku, grill akustyczny buzzera | Płasko dolnym kołnierzem do stołu |
| [`przycisk_nakladka.stl`](file:///home/tuptus/Dokumenty/PlatformIO/Projects/robot/cad_models/stl_print/przycisk_nakladka.stl) | **3 szt.** | Ergonomiczne klawisze przycisków z kołnierzem zabezpieczającym | Płasko kołnierzem do stołu |
| [`uchwyt_oled.stl`](file:///home/tuptus/Dokumenty/PlatformIO/Projects/robot/cad_models/stl_print/uchwyt_oled.stl) | 1 szt. | Wewnętrzny wspornik dociskowy ekranu OLED | Płasko na stole |
| [`robot_obudowa_kompletna.stl`](file:///home/tuptus/Dokumenty/PlatformIO/Projects/robot/cad_models/stl_print/robot_obudowa_kompletna.stl) | - | Pełne złożenie modelu klasycznego | - |

---

### ⚙️ Wersja 4: Steam-Titan Nautilus ULTRA (Katalog `cad_models/stl_print/dieselpunk/`)

| Plik STL | Ilość | Opis / Rola w konstrukcji | Orientacja na stole |
| :--- | :---: | :--- | :--- |
| [`dieselpunk_podstawa.stl`](file:///home/tuptus/Dokumenty/PlatformIO/Projects/robot/cad_models/stl_print/dieselpunk/dieselpunk_podstawa.stl) | 1 szt. | Dolne chassis kotła z 4 stopami śrubowymi, dolną żaluzją pary i szynami ESP32 | Płasko na spodzie (Z=0) |
| [`dieselpunk_glowa.stl`](file:///home/tuptus/Dokumenty/PlatformIO/Projects/robot/cad_models/stl_print/dieselpunk/dieselpunk_glowa.stl) | 1 szt. | Głowa Nautilus ULTRA: 54mm kocioł parowy, 29 nitów 3D, potrójna klatka iluminatora, podwójne kominy z potrójnymi kryzami i kołnierzami, boczne manometry (fi 21mm), rurociągi, koła zębate napędowe, mosiężne iluminatory, żaluzje chłodzące, zawory bezpieczeństwa, wieżyczka peryskopowa i tylny właz inspekcyjny | Płasko dolnym kołnierzem do stołu |
| [`dieselpunk_przycisk_zawor.stl`](file:///home/tuptus/Dokumenty/PlatformIO/Projects/robot/cad_models/stl_print/dieselpunk/dieselpunk_przycisk_zawor.stl) | 1 szt. | Środkowy przycisk: 6-ramienne mosiężne koło zaworu parowego z wieńcem i centralną nakrętką | Płasko kołnierzem do stołu |
| [`dieselpunk_przycisk_ryfel_l.stl`](file:///home/tuptus/Dokumenty/PlatformIO/Projects/robot/cad_models/stl_print/dieselpunk/dieselpunk_przycisk_ryfel_l.stl) | 1 szt. | Lewy przycisk nawigacyjny: płyta z industrialną blachą ryflowaną i chevronem `◀` | Płasko kołnierzem do stołu |
| [`dieselpunk_przycisk_ryfel_p.stl`](file:///home/tuptus/Dokumenty/PlatformIO/Projects/robot/cad_models/stl_print/dieselpunk/dieselpunk_przycisk_ryfel_p.stl) | 1 szt. | Prawy przycisk nawigacyjny: płyta z industrialną blachą ryflowaną i chevronem `▶` | Płasko kołnierzem do stołu |
| [`dieselpunk_robot_kompletny.stl`](file:///home/tuptus/Dokumenty/PlatformIO/Projects/robot/cad_models/stl_print/dieselpunk/dieselpunk_robot_kompletny.stl) | - | Pełne złożenie modelu Steam-Titan Nautilus ULTRA (do podglądu w slicerze) | - |

#### Elementy składowe dla wielomateriałowego renderera (Folder `components/`):
- `nautilus_kominy.stl` – masywne wiktoriańskie kominy z potrójnymi kryzami chłodzącymi (Mosiądz)
- `nautilus_manometry.stl` – analogowe zegary ciśnienia pary z tarczami i wskazówkami (Mosiądz)
- `nautilus_rurociagi.stl` – rurociągi parowe wysokociśnieniowe z kołnierzami (Miedź)
- `nautilus_klatka_okna.stl` – potrójna klatka ochronna iluminatora ekranu OLED (Mosiądz)
- `nautilus_kola_zebate.stl` – odsłonięty zespół przekładni zębatych napędowych (Mosiądz)
- `nautilus_iluminatory.stl` – boczne bulaje okrętowe ze śrubami ryglowymi (Mosiądz)

> [!TIP]
> W katalogu `cad_models/` znajdują się dedykowane pliki **Blender**:
> - [`robot_dieselpunk.blend`](file:///home/tuptus/Dokumenty/PlatformIO/Projects/robot/cad_models/robot_dieselpunk.blend) – gotowa scena z modelem Steam-Titan Nautilus w stylu industrial steampunk (mosiądz, miedź, patynowana stal)!
> - [`robot_dreadnought.blend`](file:///home/tuptus/Dokumenty/PlatformIO/Projects/robot/cad_models/robot_dreadnought.blend) – gotowa scena z modelem Cyber-Titan Dreadnought w kolorze Gunmetal Carbon!
> - [`robot_mecha_kawaii.blend`](file:///home/tuptus/Dokumenty/PlatformIO/Projects/robot/cad_models/robot_mecha_kawaii.blend) – gotowa scena z modelem Mecha Kawaii w kolorze Sakura!
> - [`robot_obudowa_klasyczna.blend`](file:///home/tuptus/Dokumenty/PlatformIO/Projects/robot/cad_models/robot_obudowa_klasyczna.blend) – gotowa scena z modelem Retro CRT
> - [`robot_modular_core.blend`](file:///home/tuptus/Dokumenty/PlatformIO/Projects/robot/cad_models/robot_modular_core.blend) – demonstracja stelaża Universal Core i beznarzędziowej wymiany obudów
> Dostępne są również pliki źródłowe **STEP** (`.step`) oraz parametryczne projekty **FreeCAD** (`robot_dieselpunk_3d.FCStd`, `robot_dreadnought_3d.FCStd`, `robot_mecha_kawaii_3d.FCStd`, `robot_obudowa_3d.FCStd`, `robot_core_chassis.FCStd`).

---

## ⚙️ Zalecane Parametry Slicera (Bambu Studio / OrcaSlicer / PrusaSlicer / Cura)

- **Materiał**: 
  - **PLA** (Zalecany): Najwyższa precyzja, brak skurczu, idealne pasowanie zatrzasków, kołnierzy i przycisków.
  - **PETG**: Bardzo dobra trwałość mechaniczna i odporność termiczna.
- **Średnica dyszy (Nozzle)**: `0.4 mm`
- **Wysokość warstwy (Layer height)**:
  - Obudowy (baza i głowa): `0.20 mm`
  - Przyciski taktyczne oraz detale: `0.16 mm` (dla perfekcyjnej ostrości krawędzi)
- **Ścianki / Obrysy (Perimeters / Wall loops)**: `3 lub 4` (min. 1.2–1.6 mm grubości) — gwarantuje pełną szczelność optyczną.
- **Warstwy górne i dolne (Top/Bottom layers)**: `4-5 warstw` (min. 0.8–1.0 mm).
- **Wypełnienie (Infill)**: `15% – 20%` (Zalecany wzór: **Gyroid**).
- **Podpory (Supports)**:
  - **Podstawa (Base)**: **BEZ PODPÓR (Supports: OFF)** — drukuje się w 100% na płasko.
  - **Głowa (Hood)**: Daszek blast-shield oraz boczne radiatory zaprojektowano pod bezpiecznym kątem **45°**, co drukuje się czysto bez podpór na każdej drukarce FDM.
  - **Przyciski taktyczne**: **BEZ PODPÓR** (drukowane kołnierzem do dołu na stole).

---

## 🎨 Sugestie Kolorystyczne

### 🛡️ Wersja Cyber-Titan Dreadnought
1. **Pancerz (Baza i Głowa)**: Matowy grafit / czerń węglowa (Matte Charcoal / Carbon Black) lub tytanowy szary (Gunmetal Grey).
2. **Klawisz Środkowy (Diament)**: Cyberpunkowy pomarańcz (Hazard Orange / Amber) lub złoty metalik.
3. **Klawisze Boczne (Strzałki)**: Ciemny tytan (Dark Titanium).

### 🌸 Wersja Mecha-Kawaii
1. **Korpus (Baza i Głowa)**: Pastel Sakura Pink (pudrowy róż) lub perłowa biel (Pearl White).
2. **Klawisze**: Neon fuksja (serduszko) + śmietankowa biel (łapki).

### 📺 Wersja Klasyczna Retro
1. **Korpus**: Matowy jasnoszary lub kość słoniowa (Vintage Off-White / Industrial Grey).
2. **Klawisze**: Turkusowy (Cyan), żółty lub pomarańczowy akcent retro.

---

## 🔬 Matematyczna Weryfikacja Systemu Modularnego Quick-Swap (Obliczenia CAD)

Poniższa tabela przedstawia wyniki dokładnych obliczeń booleańskich wykonanych bezpośrednio w silniku OpenCASCADE (FreeCAD) na modelach geometrycznych stelaża centralnego (`Universal Core Chassis`) oraz wszystkich 4 wersji głowic:

| Wersja Stylistyczna | Plik CAD (.FCStd) | Objętość Głowy | Liczba Brył (Solids) | Kolizja ze Stelażem | Pasowanie Kinematyczne (Z=30 $\to$ 0 mm) |
| :--- | :--- | :---: | :---: | :---: | :---: |
| **1. Retro CRT** | `robot_obudowa_3d.FCStd` | `16,009.2 mm³` | **1 (Manifold)** | **0.0000 mm³** | **Czyste (0.0000 mm³)** |
| **2. Mecha-Kawaii** | `robot_mecha_kawaii_3d.FCStd` | `19,853.5 mm³` | **1 (Manifold)** | **0.0000 mm³** | **Czyste (0.0000 mm³)** |
| **3. Cyber-Titan Apex** | `robot_dreadnought_3d.FCStd` | `33,005.3 mm³` | **1 (Manifold)** | **0.0000 mm³** | **Czyste (0.0000 mm³)** |
| **4. Steam-Titan Nautilus ULTRA** | `robot_dieselpunk_3d.FCStd` | `33,560.8 mm³` | **1 (Manifold)** | **0.0000 mm³** | **Czyste (0.0000 mm³)** |

### Precyzyjne Wymiary i Luzy Montażowe:
- **Szyny prowadzące Quick-Swap**:
  - Szyna stelaża: grubość `1.6 mm`, długość `22.0 mm`, wysokość `13.0 mm`, faza wprowadzająca $30^\circ$.
  - Rowek w głowie: szerokość `2.6 mm`, długość `24.0 mm`, głębokość `6.0 mm`.
  - **Luz roboczy**: `0.5 mm` na stronę (idealny dla technologii FDM — gładki poślizg bez oporu i zacięć).
- **Zatrzaski kulkowe (Ball Detents)**:
  - Promień kulki: `R = 0.9 mm` (fi 1.8 mm) na wysokości $Z = 9.5\text{ mm}$.
  - Zapewniają pewny, sprężysty "klik" blokujący głowę bez użycia jakichkolwiek śrub.
- **Kieszeń ekranu OLED (0.96" I2C)**:
  - Kąt pochylenia: $80^\circ$ ($-10^\circ$ od pionu).
  - Wymiary kieszeni: $28.0 \times 28.0\text{ mm}$, prześwit wokół laminatu: `2.4 mm` (zero naprężeń na szkle).
- **Kieszeń buzzera 12mm**:
  - Średnica cylindra stelaża: `14.4 mm`, kieszeń w głowie: `17.2 mm` (luz promieniowy `1.4 mm`).
- **Prowadnice przycisków**:
  - Trzpień przycisku: `fi 4.8 mm`, otwór w obudowie: `fi 6.2 mm` (**duży, płynny luz roboczy `0.7 mm` na stronę / `1.4 mm` na średnicy** — przyciski nie zakleszczają się w druku FDM, a otwory mieszczą również fabryczne nakładki 6.0 mm).
  - Oparcie kołnierza: podtoczenie `fi 8.4 mm` (kołnierz klawisza `fi 7.2 mm` nie ma prawa wypaść na zewnątrz).

---

## 🛠️ Instrukcja Montażu: Architektura Centralnego Stelaża (Złóż raz!)

Dzięki nowemu stelażowi **Universal Core Chassis**, całą elektronikę składasz i podłączasz **tylko jeden raz na stelażu**. Od tej pory zmiana obudowy na biurku zajmuje dosłownie sekundę!

### Krok 1: Przyciski Nawigacyjne (Mikrostyki 6x6 mm)
1. Wsuń 3 mikroprzełączniki Tact Switch 6x6 mm **od góry w otwarte kieszenie** przedniej belki stelaża (szerokość kieszeni 7.2 mm z bocznymi rowkami 8.6 mm na piny).
2. Trzpienie przełączników wsuwają się gładko w przednie pionowe okna U-kształtne (szerokość 4.8 mm).
3. Piny i przewody opadają wprost przez dolne okna (6.4 x 4.0 mm) do centralnego tunelu kablowego.
4. Tylna ścianka kieszeni opiera się o sztywną ścianę zderzaka – klikanie jest precyzyjne i twarde.
5. Podłącz piny: Lewy ➔ **GPIO 18**, Środkowy (OK) ➔ **GPIO 19**, Prawy ➔ **GPIO 23** (oraz wspólna masa GND).

### Krok 2: Płytka ESP32 DevKit V1
1. Wsuń płytkę ESP32 wzdłuż szyn prowadzących od tyłu (lub opuść od góry w otwarty korytarz 30mm), aż oprze się o przedni zderzak oporowy (Y=-26.0mm) i kliknie w boczne zatrzaski sprężyste na Z=7.1mm.
2. Dwa rzędy pinów goldpin (2x15) wiszą swobodnie w głębokich kanałach (4.7mm głębokości, od Z=5.5 do 0.8mm) — zero oporu i zero kolizji.
3. Przedni zderzak oporowy uniemożliwia przesunięcie płytki podczas podłączania kabla USB.
4. Port microUSB / USB-C znajduje się idealnie w tylnym oknie z fazą naprowadzającą.

### Krok 3: Czujnik Ruchu MPU-6050
1. Umieść płytkę MPU-6050 (GY-521) poziomo na mostku sensorycznym stelaża (Z=12.0mm ponad ESP32) i opcjonalnie zabezpiecz 2 śrubkami M2.5 (rozstaw 15.2mm).
2. Wyprowadź przewody magistrali I2C (**SDA: GPIO 21**, **SCL: GPIO 22**, zasilanie 3.3V i GND) przez przedni przepust kablowy prosto do centralnego kanału pod ESP32.

### Krok 4: Wyświetlacz OLED 0.96" na Wzmocnionym Maszcie (v2.3)
1. Włóż moduł OLED 0.96" SSD1306 do dedykowanej kieszeni (27.6 x 27.6 mm) ukośnego masztu (nachylenie 80° / -10° od pionu).
2. Płytka lica opiera się gładko w gnieździe — tylne okno (20.0 x 16.0 mm) chroni drobne rezystory/kondensatory SMD przed jakimkolwiek dociskiem mechanicznym, a dolna szczelina (16.0 x 2.5 mm) całkowicie zabezpiecza taśmę giętką FPC szkła OLED przed załamaniem.
3. Przykręć płytkę 2 lub 4 krótkimi wkrętami samogwintującymi **M2** (długość 4–6 mm) w fabryczne otwory pilotowe (fi 1.8 mm x 4.5 mm, rozstaw standardowy 23.5 x 23.5 mm). Koniec z ułamywaniem plastikowych bolców!
4. Podłącz przewody I2C (**VCC**, **GND**, **SCL: GPIO 22**, **SDA: GPIO 21**) przez górne poszerzone wycięcie (14.0 x 5.5 mm) – swobodnie mieszczą się tam zarówno złącza żeńskie goldpin, jak i piny kątowe.

### Krok 5: Buzzer Piezoelektryczny 12 mm
1. Wciśnij przetwornik buzzer 12mm od góry w cylindryczny koszyk na szczycie wieży (press-fit na klik).
2. Przełóż wyprowadzenia przez dolny kanał kablowy prosto do pinu **GPIO 25** i GND.
3. Buzzer skierowany jest ku górze, wprost w szczeliny akustyczne dachu robota!

### Krok 6: Podklejenie nóżek antypoślizgowych
1. Wklej 4 silikonowe nóżki (fi 8 mm) w gniazda na spodzie stelaża. Stelaż stoi stabilnie na biurku.

---

## 🎭 Błyskawiczna Wymiana Obudów (Quick-Swap / Slide-On)

1. Wybierz dowolną obudowę górną (**Retro CRT**, **Mecha-Kawaii** lub **Cyber-Titan Apex**).
2. Wsuń od środka w otwory czołowe danej obudowy jej stylizowane nakładki przycisków (kołnierz zabezpiecza je przed wypadnięciem na zewnątrz).
3. Nałóż obudowę od góry na stelaż – wewnętrzne szyny prowadzące gładko poprowadzą obudowę w dół, a dolne zatrzaski kulkowe (snap-detents) klikną w dolnym położeniu.
4. **Chcesz zmienić wygląd robota?** Po prostu pociągnij głowę w górę i nałóż inną! Wszystkie kable, ekran, ESP32 i buzzer zostają nienaruszone na biurku!

---

## 🚀 Gotowe!
Podłącz kabel USB z tyłu robota, wgraj kod (`pio run -t upload`) i ciesz się w pełni modułowym, niesamowitym robotem biurkowym!

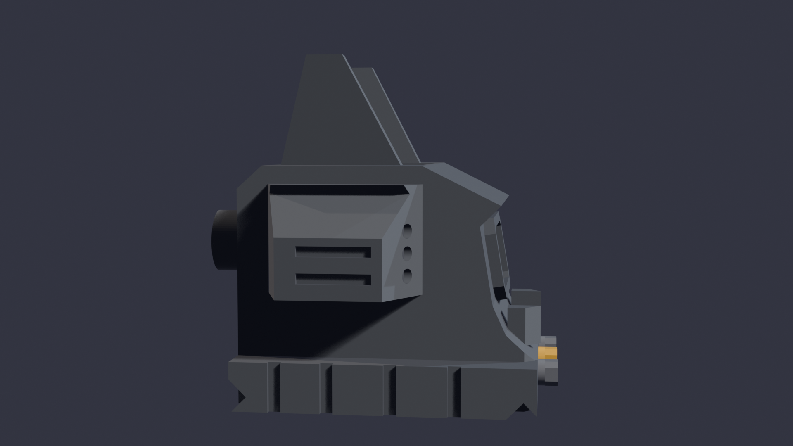
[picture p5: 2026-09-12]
cad_models/podglad_dreadnought_profil.png

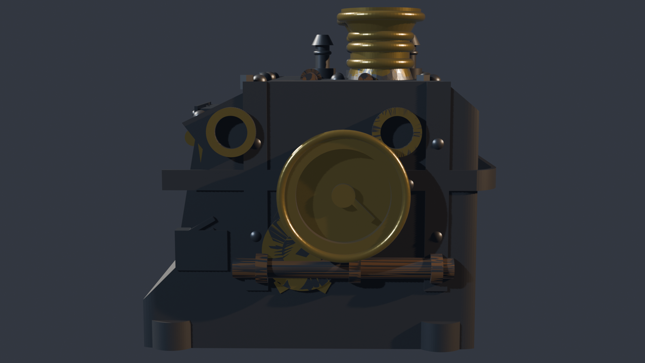
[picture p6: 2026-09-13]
cad_models/podglad_dieselpunk_profil.png

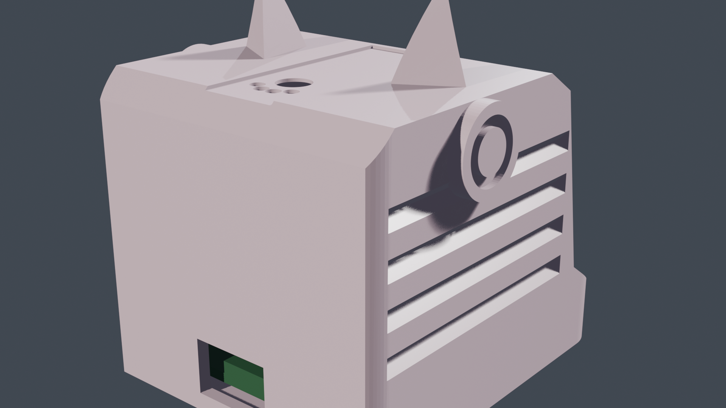
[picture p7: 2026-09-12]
cad_models/podglad_mecha_kawaii_tyl.png

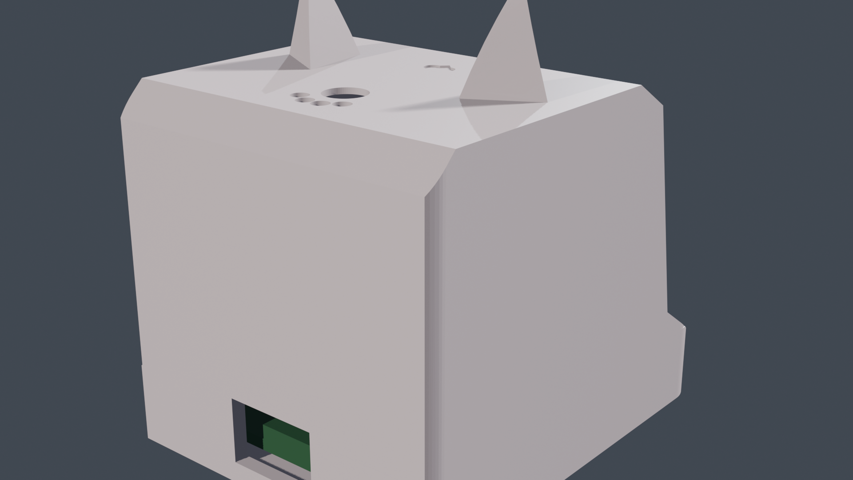
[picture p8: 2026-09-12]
cad_models/podglad_kawaii_tyl.png

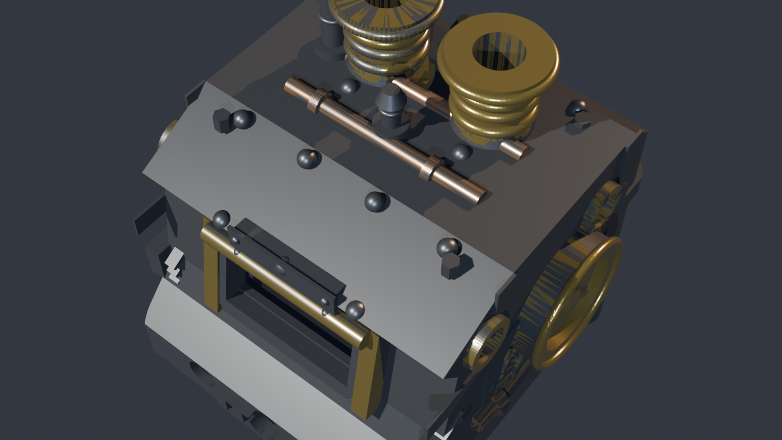
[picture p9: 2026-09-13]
cad_models/podglad_dieselpunk_gora.png

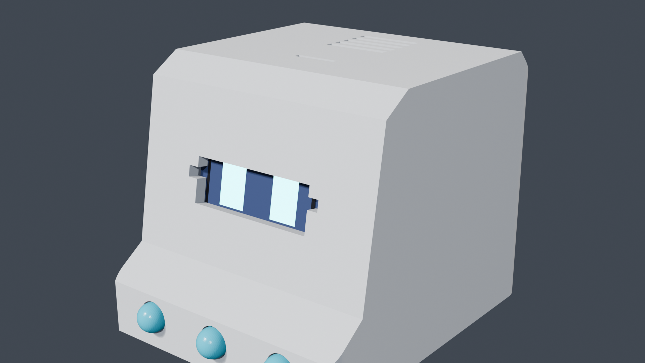
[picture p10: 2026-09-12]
cad_models/podglad_obudowy_3d.png

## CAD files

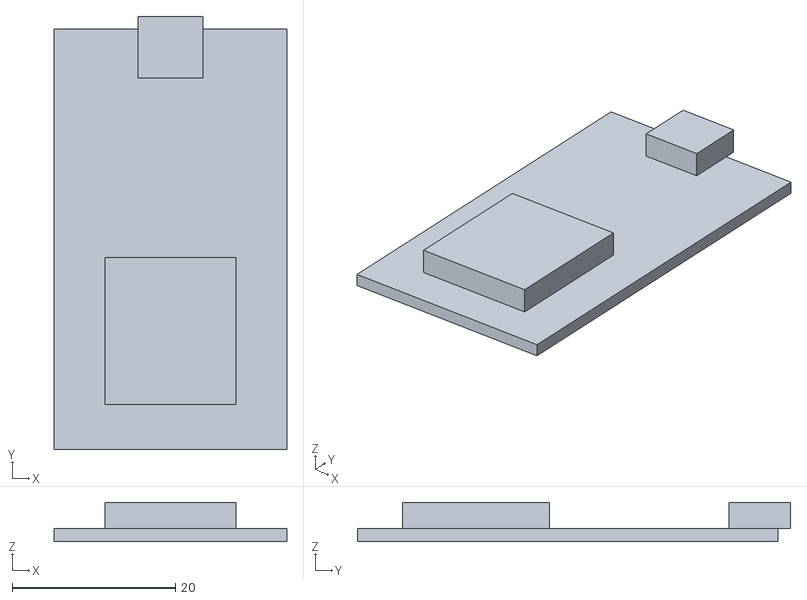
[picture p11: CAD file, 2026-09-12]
cad_models/blender_models/ESP32_Podstawa.stl
28.5 x 53.0 x 4.80

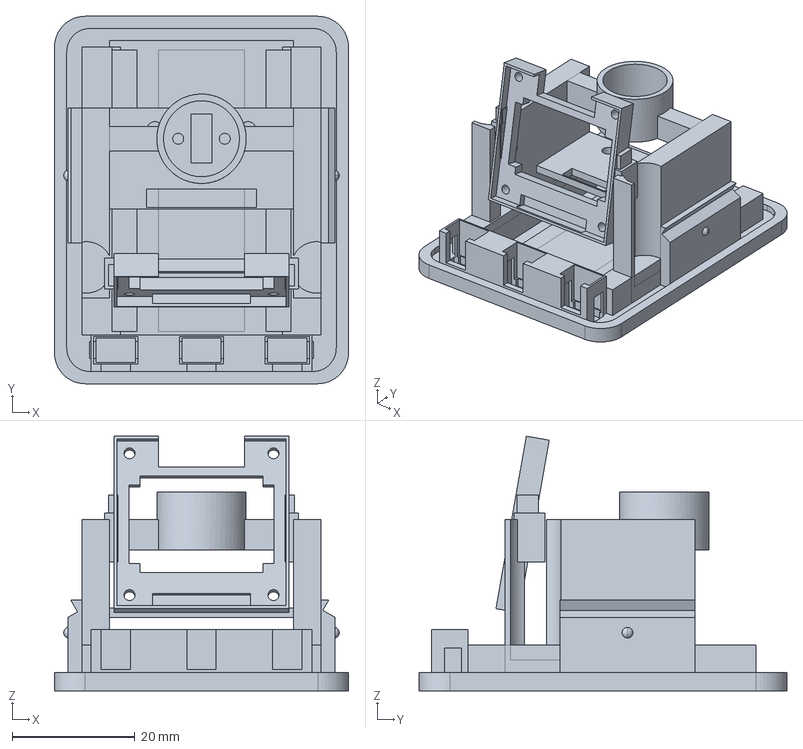
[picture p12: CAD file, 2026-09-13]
cad_models/robot_core_chassis.FCStd
48.0 x 60.0 x 41.6 mm

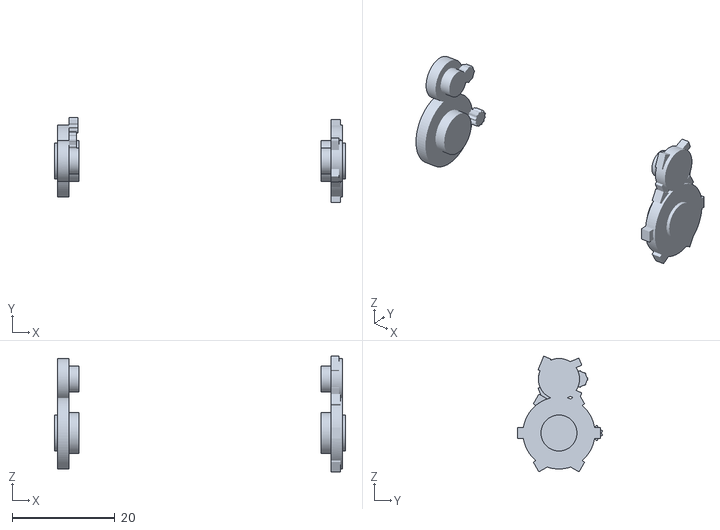
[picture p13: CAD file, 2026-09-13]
cad_models/stl_print/dieselpunk/components/nautilus_kola_zebate.stl
56.6 x 16.6 x 22.5

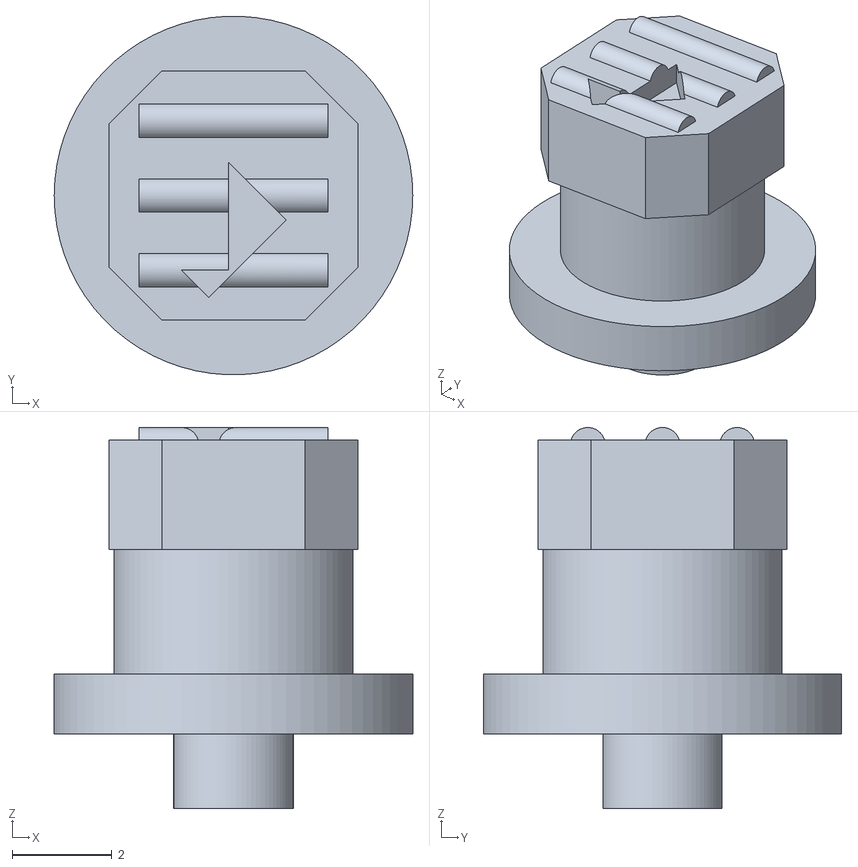
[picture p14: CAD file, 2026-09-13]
cad_models/stl_print/dieselpunk/dieselpunk_przycisk_ryfel_p.stl
7.20 x 7.19 x 7.65

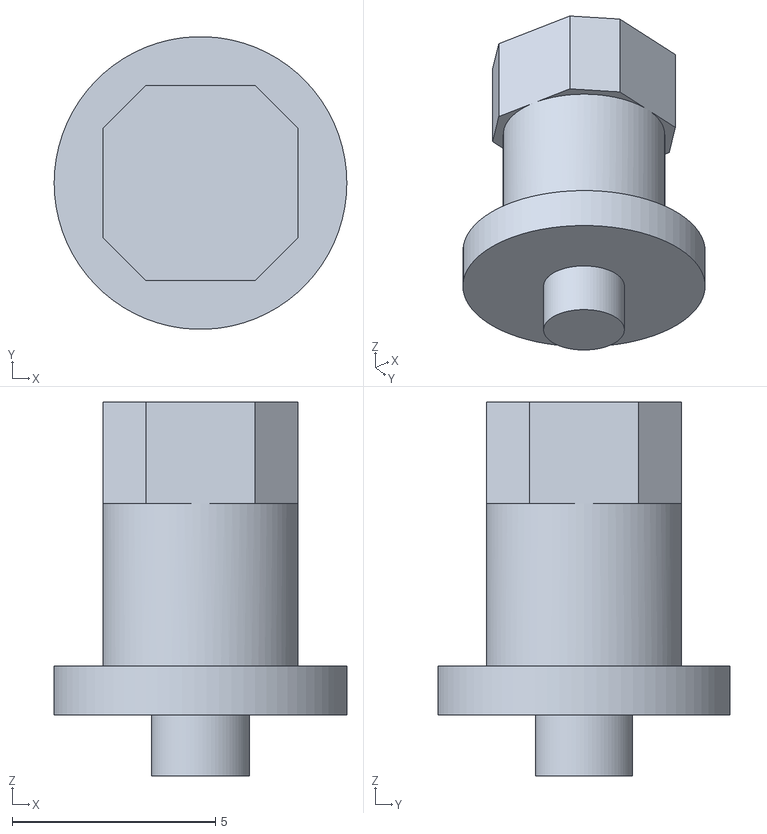
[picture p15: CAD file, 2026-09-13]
cad_models/stl_print/dreadnought/dreadnought_przycisk_strzalka_p.stl
7.20 x 7.19 x 9.20

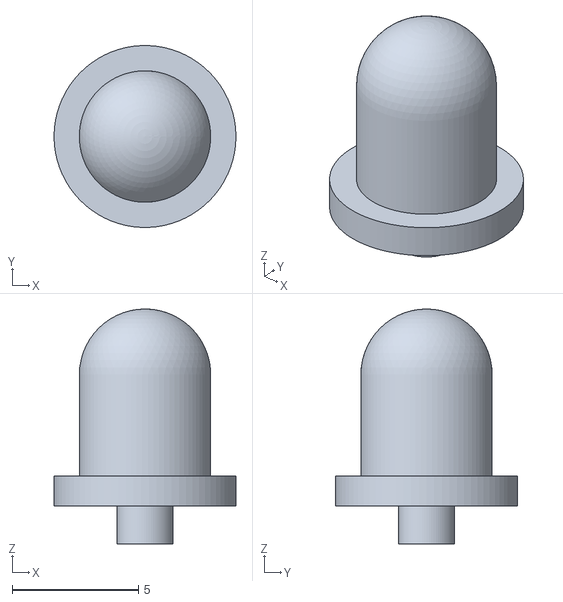
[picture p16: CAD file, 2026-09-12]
cad_models/stl_print/kawaii/kawaii_przycisk_serce.stl
7.20 x 7.19 x 9.30

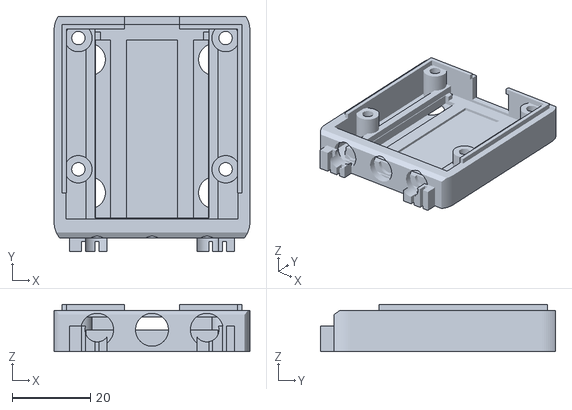
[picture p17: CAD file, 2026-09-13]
cad_models/stl_print/mecha_kawaii/mecha_kawaii_podstawa.stl
50.0 x 60.0 x 12.1

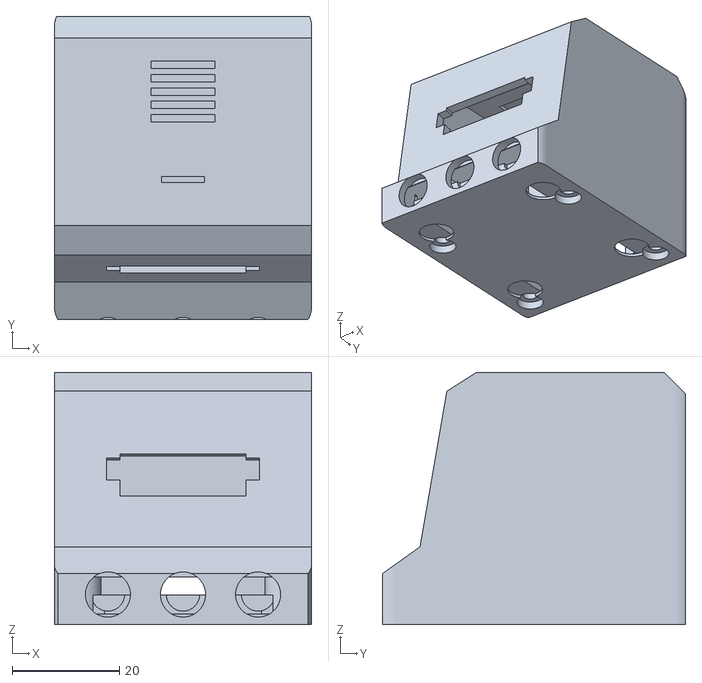
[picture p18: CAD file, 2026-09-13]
cad_models/stl_print/robot_obudowa_kompletna.stl
48.0 x 56.5 x 47.0

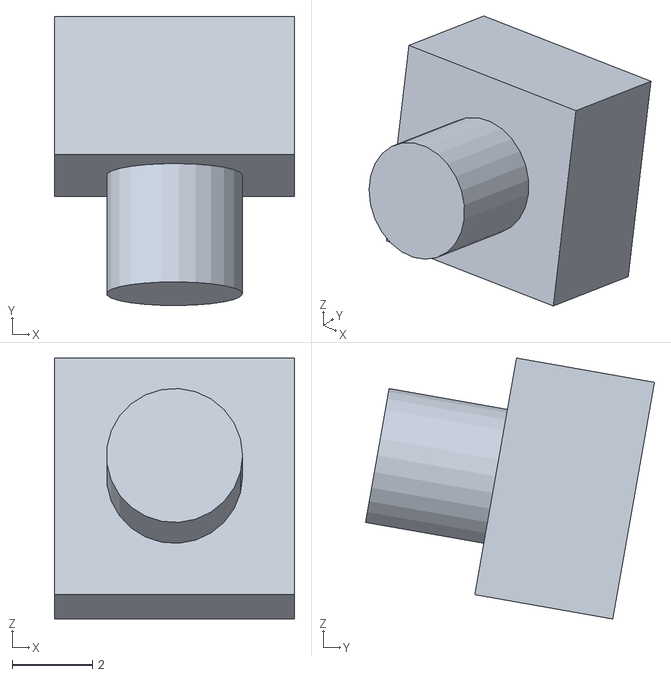
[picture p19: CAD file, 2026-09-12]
cad_models/blender_models/Przycisk_OK.stl
6.00 x 7.22 x 6.52

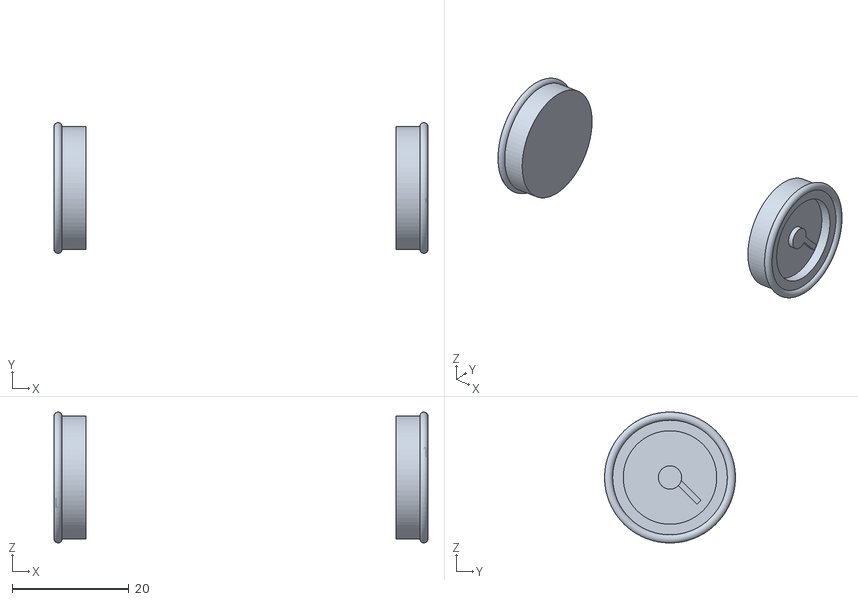
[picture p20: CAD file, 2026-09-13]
cad_models/stl_print/dieselpunk/components/nautilus_manometry.stl
64.0 x 22.4 x 22.4

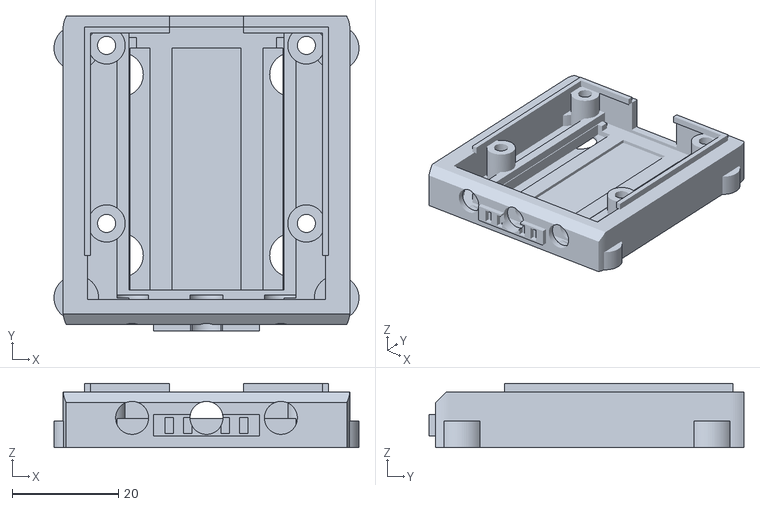
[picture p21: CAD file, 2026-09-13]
cad_models/stl_print/dieselpunk/dieselpunk_podstawa.stl
57.4 x 59.2 x 12.1

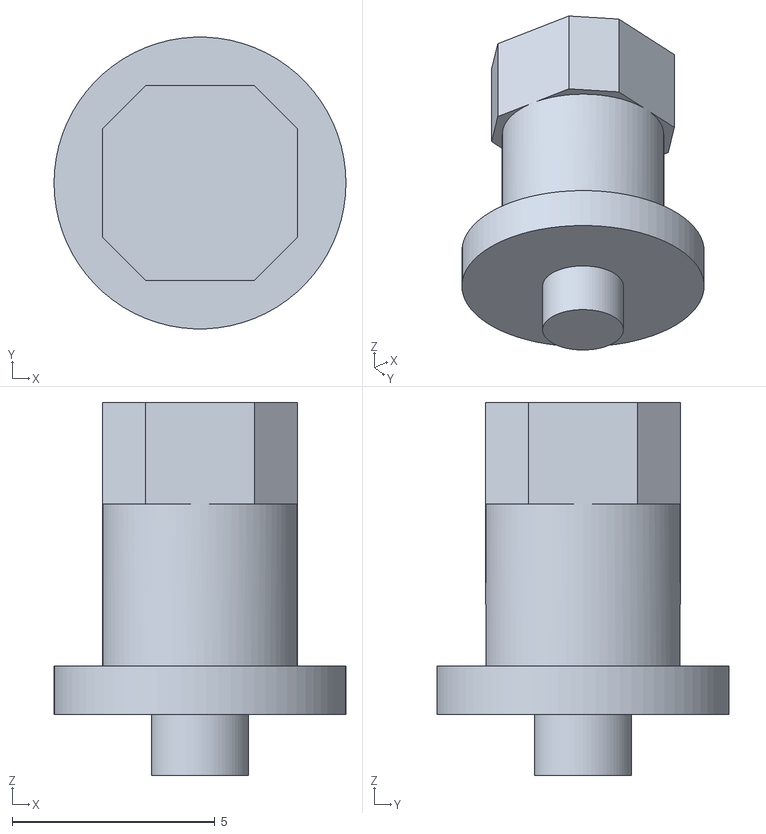
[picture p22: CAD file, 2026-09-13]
cad_models/stl_print/dreadnought/dreadnought_przycisk_romb.stl
7.20 x 7.19 x 9.20

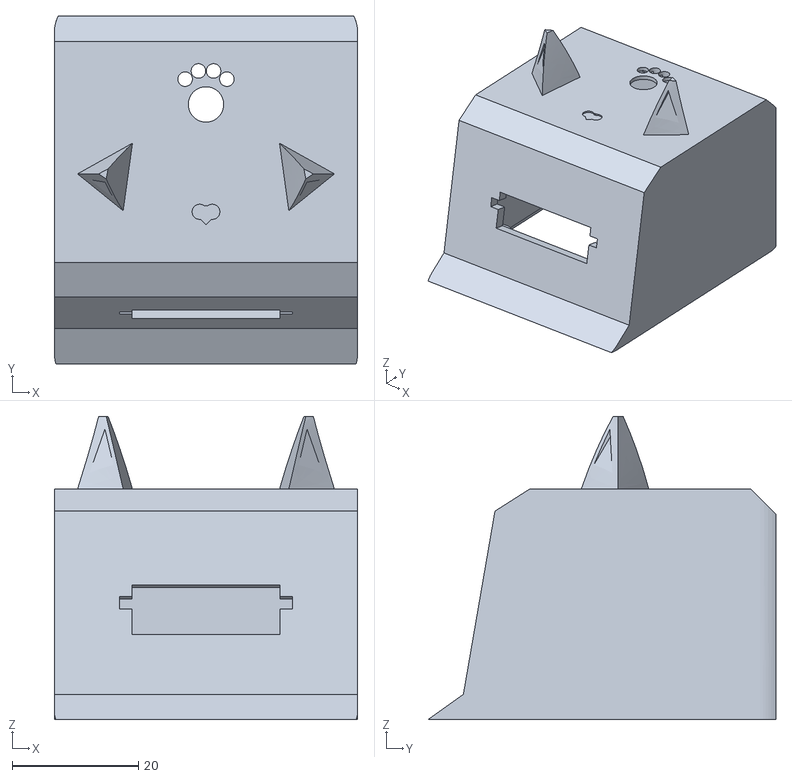
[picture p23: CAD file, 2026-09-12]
cad_models/stl_print/kawaii/kawaii_obudowa_gora_glowa.stl
48.0 x 55.1 x 48.0

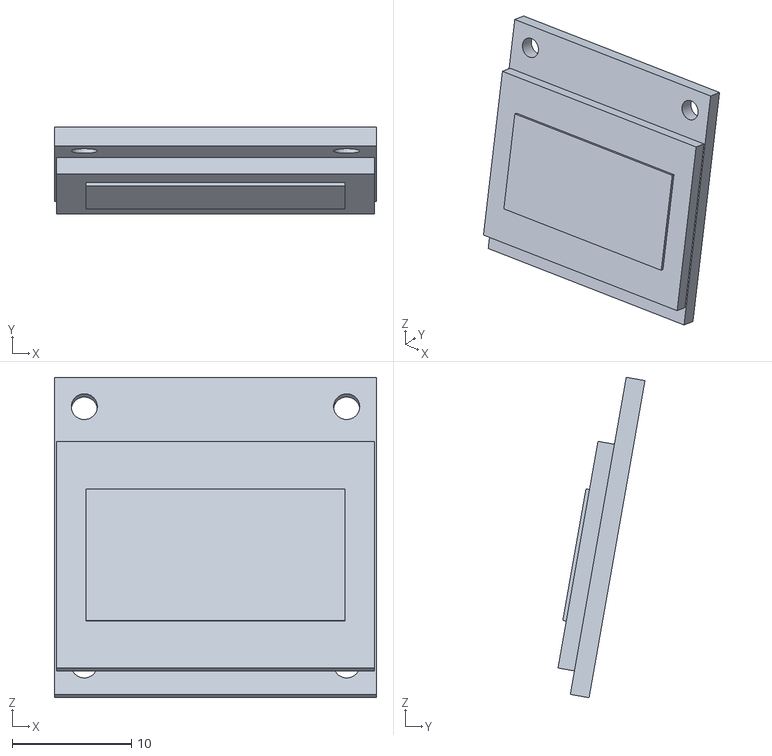
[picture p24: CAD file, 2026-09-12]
cad_models/blender_models/OLED_Twarz.stl
27.0 x 7.30 x 26.9

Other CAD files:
cad_models/core_chassis.step
cad_models/stl_print/mecha_kawaii/mecha_kawaii_przycisk_lapka.stl
cad_models/mecha_kawaii_glowa.step
cad_models/stl_print/dieselpunk/components/nautilus_kominy.stl
cad_models/blender_models/Buzzer.stl
cad_models/blender_models/MPU6050_Ruch.stl
cad_models/blender_models/Przycisk_Lewo.stl
cad_models/blender_models/Przycisk_Prawo.stl
cad_models/blender_models/robot_caly_szkielet.stl
cad_models/buzzer_12mm.step
cad_models/dieselpunk_glowa.step
cad_models/dieselpunk_podstawa.step
cad_models/dieselpunk_przycisk_ryfel_l.step
cad_models/dieselpunk_przycisk_ryfel_p.step
cad_models/dieselpunk_przycisk_zawor.step
cad_models/dieselpunk_robot_zlozenie.step
cad_models/dreadnought_glowa.step
cad_models/dreadnought_podstawa.step
cad_models/dreadnought_przycisk_romb.step
cad_models/dreadnought_przycisk_strzalka_l.step
cad_models/dreadnought_przycisk_strzalka_p.step
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

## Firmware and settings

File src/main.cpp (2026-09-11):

#include <Arduino.h>
#include <Wire.h>
#include <Adafruit_GFX.h>
#include <Adafruit_SSD1306.h>
#include <Adafruit_MPU6050.h>
#include <Adafruit_Sensor.h>

#define SCREEN_WIDTH 128
#define SCREEN_HEIGHT 64

#define BUZZER_PIN 25
#define CHARGER_PIN 34   // Podłączone do przełącznika USB-C (lub potencjometru)
#define SHAKE_BTN_PIN 13 // Przycisk SHAKE w Wokwi (klikasz myszką!)
#define BTN_LEFT_PIN 18  // Przycisk LEWO (niebieski)
#define BTN_OK_PIN 19    // Przycisk OK (żółty)
#define BTN_RIGHT_PIN 23 // Przycisk PRAWO (czerwony)
#define TOUCH_FRONT_PIN 32 // Pasek dotykowy A: Przód głowy (ESP32 Touch 9)
#define TOUCH_BACK_PIN  33 // Pasek dotykowy B: Tył głowy (ESP32 Touch 8)
#define TOUCH_THRESHOLD 40 // Próg detekcji zbliżenia dłoni (< 40 = dotyk)
#include <esp_system.h>

// Flagi automatycznego wykrywania środowiska i sprzętu
bool isWokwiEnvironment = false;
bool hasMpuSensor = false;

// Dynamiczna autokalibracja dotyku pojemnościowego na fizycznym ESP32
int touchBaselineFront = 75;
int touchBaselineBack = 75;
int touchThresholdFront = 40;
int touchThresholdBack = 40;

Adafruit_SSD1306 display(SCREEN_WIDTH, SCREEN_HEIGHT, &Wire, -1);
Adafruit_MPU6050 mpu;

// --- STANY ROBOTA ---
enum RobotState {
  STATE_SLEEP,            // Robot śpi, zamknięte oczka
  STATE_AWAKE,            // Wybudzony, mruga, reaguje na potrząsanie (po 2s)
  STATE_HAPPY_PET,        // Pogłaskany po głowie: mruczenie, serduszka, szczęśliwe oczka
  STATE_LOW_BATTERY_SAD,  // Smutne, zmęczone oczka + smutny dźwięk
  STATE_LOW_BATTERY_ICON, // Duża ikona pustej baterii z wykrzyknikiem
  STATE_DEAD_SLEEP,       // Całkowicie rozładowany (brak reakcji na potrząsanie)
  STATE_CHARGING,         // Podłączony do kabla USB-C, animacja ładowania
  STATE_MENU,             // Menu główne
  STATE_SUB_EYES,         // Wybór stylu i koloru oczu
  STATE_SUB_PC_MONITOR,   // Monitor podzespołów PC
  STATE_SUB_POMODORO,     // Czasomierz Pomodoro
  STATE_SUB_GAME          // Mini-gra Dino-Robot Jump
};

RobotState currentState = STATE_SLEEP;

// --- MOTYWY I KSZTAŁTY OCZÓW ---
enum EyeTheme {
  THEME_CLASSIC = 0,   // Białe oczy na czarnym tle
  THEME_INVERT,        // Negatyw / Cyber: Czarne oczy na białym tle
  THEME_NEON,          // Obwódka neonowa (kontur)
  THEME_SCANLINES      // Paski skanera CRT
};
const int THEME_COUNT = 4;
const char* const themeNames[] = {"Classic", "Invert", "Neon", "Scanlines"};

enum EyeShape {
  SHAPE_DEFAULT = 0,   // Standard rounded
  SHAPE_CAT,           // Cat slit eyes
  SHAPE_CYBER,         // Cyber angular
  SHAPE_HEARTS,        // Heart eyes
  SHAPE_ANIME          // Anime sparkle
};
const int SHAPE_COUNT = 5;
const char* const shapeNames[] = {"Standard", "Cat Eyes", "Cyber", "Hearts", "Anime"};

int currentTheme = THEME_CLASSIC;
int currentShape = SHAPE_DEFAULT;

// --- MAIN MENU ---
const char* const menuItems[] = {
  "1. Eye Style",
  "2. Pomodoro",
  "3. Dino Jump",
  "4. Exit Menu"
};
const int MENU_ITEMS_COUNT = 4;
int currentMenuIndex = 0;

// --- STATYSTYKI MONITOROWANIA PC ---
float pcCpu = 45.0f;
float pcRam = 58.0f;
float pcGpu = 62.0f;
float pcTemp = 56.0f;
unsigned long lastPcPacketTime = 0;

// --- CZASOMIERZ POMODORO ---
unsigned long pomodoroSecondsLeft = 25 * 60; // 25 minut
bool pomodoroRunning = false;
unsigned long lastPomodoroTick = 0;

// --- MINI-GRA DINO JUMP ---
float gamePlayerY = 44.0f;
float gamePlayerVy = 0.0f;
bool gameIsJumping = false;
int gameObstacleX = 128;
int gameObstacleW = 8;
int gameObstacleH = 12;
int gameScore = 0;
bool isGameOver = false;
unsigned long lastGameTick = 0;

// --- OBSŁUGA PRZYCISKÓW ---
bool lastBtnLeft = false, lastBtnOk = false, lastBtnRight = false;
unsigned long timeBtnLeft = 0, timeBtnOk = 0, timeBtnRight = 0;

// --- PROTOTYPY FUNKCJI ---
void soundWakeUp();
void soundSleep();
void soundSadBattery();
void soundChargerPlugged();
void soundFullyCharged();
void soundNavClick();
void soundConfirm();
void soundBack();
void soundPurr();
void soundSurprised();
void drawEyes(int eyeHeight, int offsetX = 0, int offsetY = 0);
void drawSingleEye(int x, int y, int w, int h, int shape, int theme);
void drawSleepEyes(int sleepPhase = 2);
void drawSadTiredEyes();
void drawBigEmptyBattery(bool blink);
void drawBigChargingBattery(int percent, int frame);
void drawMiniHeart(int x, int y);
void drawSmilingEye(int cx, int cy, int w, int h, int theme);
void drawHappyPetEyes(unsigned long elapsed, bool reverse = false);
void triggerHappyPet(bool reverse = false);
bool isPadTouched(int pin);
void handleTouchGestures();
void playWakeUpAnimation();
void playSleepAnimation();
void triggerShake();
void handleSerialCommands();
void turnScreenOff();
void turnScreenOn();
void drawMenuScreen();
void drawEyesSubMenu();
void drawPcMonitorScreen();
void drawPomodoroScreen();
void drawGameScreen();
void updatePcStats();
void updateGame();
void handleIdleEyes(unsigned long now);
bool isLeftPressed();
bool isOkPressed();
bool isRightPressed();

// --- CZASY I COOLDOWNY ---
unsigned long wakeUpTimestamp = 0;       // Czas ostatniego wybudzenia
unsigned long stateChangeTimestamp = 0;  // Czas wejścia w bieżący stan
unsigned long lastBlinkTime = 0;
unsigned long nextIdleActionTime = 0;    // Czas do kolejnego spojrzenia/mrugnięcia w bezczynności
unsigned long lastBatteryTick = 0;
unsigned long lastAnimTick = 0;
unsigned long lastSleepAnimTick = 0;
unsigned long lastShakeTime = 0;
unsigned long fullChargeTimestamp = 0;
int sleepAnimPhase = 2;
bool isScreenTurnedOff = false;          // Flaga całkowitego wyłączenia ekranu po 5s snu
const unsigned long WAKE_IGNORE_DURATION = 2000; // 2 sekundy ignorowania potrząsania po obudzeniu
const unsigned long SHAKE_DEBOUNCE = 600;

// --- GEST GŁASKANIA (TOUCH 32 / 33) ---
unsigned long lastTouchFrontTime = 0;
unsigned long lastTouchBackTime = 0;
unsigned long touchCooldownUntil = 0;
unsigned long happyPetStartTime = 0;
unsigned long lastPurrTick = 0;
bool isHappySurprised = false;
bool lastPadF = false;
bool lastPadB = false;

// --- BATERIA I SYMULACJA ŁADOWANIA ---
float batteryPercent = 100.0f;          // Pełna bateria (100%) - nie rozładuje się natychmiast podczas testów!
bool isUsbConnected = false;
bool wasUsbConnected = false;
int virtualUsb = -1;                    // -1: tryb automatyczny (przełącznik w Wokwi), 1: wymuszone USB ON, 0: wymuszone USB OFF
int animFrame = 0;


// ==========================================
// DŹWIĘKI (BUZZER)
// ==========================================
void soundWakeUp() {
  tone(BUZZER_PIN, 600, 80);
  delay(90);
  tone(BUZZER_PIN, 900, 80);
  delay(90);
  tone(BUZZER_PIN, 1300, 150);
}

void soundSleep() {
  tone(BUZZER_PIN, 1000, 100);
  delay(120);
  tone(BUZZER_PIN, 500, 220);
}

void soundSadBattery() {
  tone(BUZZER_PIN, 850, 180);
  delay(200);
  tone(BUZZER_PIN, 650, 180);
  delay(200);
  tone(BUZZER_PIN, 480, 220);
  delay(240);
  tone(BUZZER_PIN, 300, 400);
}

void soundChargerPlugged() {
  // Radosny dwuton jak podłączenie iPhone'a / Switcha
  tone(BUZZER_PIN, 523, 100); // C5
  delay(110);
  tone(BUZZER_PIN, 659, 100); // E5
  delay(110);
  tone(BUZZER_PIN, 784, 200); // G5
}

void soundFullyCharged() {
  tone(BUZZER_PIN, 659, 90);
  delay(100);
  tone(BUZZER_PIN, 784, 90);
  delay(100);
  tone(BUZZER_PIN, 1046, 250);
}

void soundNavClick() {
  tone(BUZZER_PIN, 1500, 20);
}

void soundConfirm() {
  tone(BUZZER_PIN, 1800, 35);
  delay(40);
  tone(BUZZER_PIN, 2400, 55);
}

void soundBack() {
  tone(BUZZER_PIN, 900, 30);
  delay(35);
  tone(BUZZER_PIN, 650, 40);
}

// Przyjemne mruczenie zadowolonego robota
void soundPurr() {
  for (int i = 0; i < 3; i++) {
    tone(BUZZER_PIN, 320, 25);
    delay(35);
    tone(BUZZER_PIN, 280, 25);
    delay(35);
  }
}

// Zaskoczony, wysoki dźwięk "bip-bip?!" przy głaskaniu pod włos
void soundSurprised() {
  tone(BUZZER_PIN, 750, 60);
  delay(70);
  tone(BUZZER_PIN, 1500, 110);
}

// ==========================================
// OBSŁUGA 3 PRZYCISKÓW (LEWO, OK, PRAWO)
// ==========================================
bool checkBtn(uint8_t pin, bool &lastState, unsigned long &lastTime) {
  unsigned long now = millis();
  bool current = (digitalRead(pin) == LOW);
  bool triggered = false;
  if (current && !lastState && (now - lastTime > 160)) {
    triggered = true;
    lastTime = now;
  }
  lastState = current;
  return triggered;
}

bool isLeftPressed()  { return checkBtn(BTN_LEFT_PIN, lastBtnLeft, timeBtnLeft); }
bool isOkPressed()    { return checkBtn(BTN_OK_PIN, lastBtnOk, timeBtnOk); }
bool isRightPressed() { return checkBtn(BTN_RIGHT_PIN, lastBtnRight, timeBtnRight); }

// ==========================================
// GRAFIKA EKRANU (OLED SSD1306)
// ==========================================

void turnScreenOff() {
  if (!isScreenTurnedOff) {
    isScreenTurnedOff = true;
    display.clearDisplay();
    display.display();
    display.ssd1306_command(SSD1306_DISPLAYOFF);
    Serial.println("[EKRAN] --> 5 sekund minelo: Ekran calkowicie zgaszony (tryb uspienia OLED).");
  }
}

void turnScreenOn() {
  if (isScreenTurnedOff) {
    isScreenTurnedOff = false;
    display.ssd1306_command(SSD1306_DISPLAYON);
    Serial.println("[EKRAN] --> Wlaczenie ekranu (OLED ON).");
  }
}

// Rysowanie pojedynczego oka z płynną animacją otwierania i zamykania powiek
void drawSingleEye(int x, int y, int w, int h, int shape, int theme) {
  uint16_t color = (theme == THEME_INVERT) ? SSD1306_BLACK : SSD1306_WHITE;
  uint16_t invColor = (theme == THEME_INVERT) ? SSD1306_WHITE : SSD1306_BLACK;

  // 1. Gdy oko jest całkowicie lub niemal całkowicie zamknięte (h <= 3)
  if (h <= 3) {
    if (shape == SHAPE_CYBER) {
      display.drawFastHLine(x, y + 1, w, color);
      display.drawFastHLine(x + 1, y, w - 2, color);
    } else if (shape == SHAPE_CAT) {
      display.drawFastHLine(x + 3, y + 1, w - 6, color);
      display.drawPixel(x + 1, y, color);
      display.drawPixel(x + 2, y + 1, color);
      display.drawPixel(x + w - 3, y + 1, color);
      display.drawPixel(x + w - 2, y, color);
    } else if (shape == SHAPE_HEARTS) {
      display.drawFastHLine(x + 2, y + 1, w / 2 - 4, color);
      display.drawFastHLine(x + w / 2 + 2, y + 1, w / 2 - 4, color);
      display.drawPixel(x + 1, y, color);
      display.drawPixel(x + w / 2 + 1, y, color);
    } else {
      display.fillRoundRect(x, y, w, max(2, h), 1, color);
    }
    return;
  }

  // 2. Kształt: STANDARD
  if (shape == SHAPE_DEFAULT) {
    int r = min(8, h / 2);
    if (theme == THEME_NEON) {
      display.drawRoundRect(x, y, w, h, r, color);
      if (w > 4 && h > 4) display.drawRoundRect(x + 1, y + 1, w - 2, h - 2, max(1, r - 1), color);
    } else {
      display.fillRoundRect(x, y, w, h, r, color);
    }
  }

  // 3. Kształt: KOCIE OCZY (CAT EYES)
  else if (shape == SHAPE_CAT) {
    int r = min(12, h / 2);
    if (theme == THEME_NEON) {
      display.drawRoundRect(x, y, w, h, r, color);
    } else {
      display.fillRoundRect(x, y, w, h, r, color);
    }
    // Źrenica zwęża się płynnie wraz ze zmianą wysokości oka
    if (h > 6) {
      int slitW = max(2, (int)(w * 0.12f));
      int slitH = max(3, h - 5);
      int slitX = x + (w - slitW) / 2;
      int slitY = y + (h - slitH) / 2;
      display.fillRoundRect(slitX, slitY, slitW, slitH, 1, invColor);
    }
  }

  // 4. Kształt: CYBER ROBOT
  else if (shape == SHAPE_CYBER) {
    if (theme == THEME_NEON) {
      display.drawRect(x, y, w, h, color);
      if (w > 4 && h > 4) display.drawRect(x + 1, y + 1, w - 2, h - 2, color);
    } else {
      display.fillRect(x, y, w, h, color);
      if (h > 8) {
        int cut = min(4, h / 4);
        display.fillTriangle(x, y, x + cut, y, x, y + cut, invColor);
        display.fillTriangle(x + w - 1, y, x + w - 1 - cut, y, x + w - 1, y + cut, invColor);
        display.fillTriangle(x, y + h - 1, x + cut, y + h - 1, x, y + h - 1 - cut, invColor);
        display.fillTriangle(x + w - 1, y + h - 1, x + w - 1 - cut, y + h - 1, x + w - 1, y + h - 1 - cut, invColor);
      }
    }
  }

  // 5. Kształt: SERDUSZKA (HEARTS)
  else if (shape == SHAPE_HEARTS) {
    if (h < 10) {
      display.fillRoundRect(x, y, w, h, 2, color);
    } else {
      int r = min(w / 4, h / 3);
      int cx1 = x + w / 4;
      int cx2 = x + 3 * w / 4;
      int cy = y + r;
      display.fillCircle(cx1, cy, r, color);
      display.fillCircle(cx2, cy, r, color);
      display.fillTriangle(x, cy + r / 2, x + w - 1, cy + r / 2, x + w / 2, y + h - 1, color);
    }
  }

  // 6. Kształt: ANIME (Z gwiazdkami i blaskiem)
  else if (shape == SHAPE_ANIME) {
    int r = min(8, h / 2);
    display.fillRoundRect(x, y, w, h, r, color);
    if (h > 10) {
      int sparkleR = max(1, min(4, h / 7));
      display.fillCircle(x + w - 8, y + (h * 0.28f), sparkleR, invColor);
      if (h > 18) {
        display.fillCircle(x + 8, y + (h * 0.72f), max(1, sparkleR - 2), invColor);
      }
    }
  }

  // Efekt Scanlines (linie skanera CRT)
  if (theme == THEME_SCANLINES && h > 5) {
    for (int line = y + 2; line < y + h; line += 3) {
      display.drawFastHLine(x, line, w, invColor);
    }
  }
}
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
void loop() {
  unsigned long now = millis();

  // 1. Obsługa poleceń z konsoli Wokwi Terminal
  handleSerialCommands();

  // 1b. Odczyt 3 przycisków fizycznych (LEWO, OK, PRAWO)
  bool btnLeftHit = isLeftPressed();
  bool btnOkHit = isOkPressed();
  bool btnRightHit = isRightPressed();

  // 2. Odczyt stanu zasilania / ładowania USB-C
  if (isWokwiEnvironment) {
    int rawCharger = analogRead(CHARGER_PIN);
    bool physicalUsbOn = (rawCharger > 2000);
    if (virtualUsb == 1) {
      isUsbConnected = true;
    } else if (virtualUsb == 0) {
      isUsbConnected = false;
    } else {
      isUsbConnected = physicalUsbOn;
    }
  } else {
    // Na fizycznym ESP32: zasilany z portu USB
    if (virtualUsb == 0) isUsbConnected = false;
    else isUsbConnected = true;
  }

  // Wykrycie momentu podłączenia kabla USB-C
  if (isUsbConnected && !wasUsbConnected) {
    Serial.println("\n[USB-C] --> PODLACZONO KABEL USB-C! Ladowanie startuje...");
    turnScreenOn();
    wasUsbConnected = true;
    currentState = STATE_CHARGING;
    stateChangeTimestamp = now;
    fullChargeTimestamp = now;
    soundChargerPlugged();
  } else if (!isUsbConnected && wasUsbConnected) {
    Serial.println("\n[USB-C] --> ODLACZONO KABEL USB-C!");
    wasUsbConnected = false;
    if (currentState == STATE_CHARGING) {
      if (batteryPercent > 20.0f) {
        currentState = STATE_AWAKE;
        wakeUpTimestamp = now;
        stateChangeTimestamp = now;
        drawEyes(36, 0, 0);
      } else {
        currentState = STATE_DEAD_SLEEP;
        stateChangeTimestamp = now;
        drawSleepEyes(2);
      }
    }
  }

  // 3. Obsługa akcelerometru MPU6050 (fizyczne potrząsanie)
  bool mpuShake = false;
  if (hasMpuSensor) {
    sensors_event_t a, g, temp;
    mpu.getEvent(&a, &g, &temp);
    float totalAccel = sqrt(a.acceleration.x * a.acceleration.x +
                            a.acceleration.y * a.acceleration.y +
                            a.acceleration.z * a.acceleration.z);
    if (totalAccel > 15.0) {
      mpuShake = true;
    }
  }

  // Wstrząs gdy przeciążenie > 15 m/s² LUB wciśnięto zielony przycisk SHAKE
  bool buttonShake = (digitalRead(SHAKE_BTN_PIN) == LOW);
  if (mpuShake || buttonShake) {
    triggerShake();
  }

  // 3b. Obsługa gestów dotykowych (głaskanie obudowy robota)
  handleTouchGestures();

  // 4. Maszyna stanów i obsługa baterii / menu
  switch (currentState) {
    
    // --- ROBOT ŚPI ---
    case STATE_SLEEP:
      // Kliknięcie dowolnego z 3 przycisków również wybudza robota!
      if (btnOkHit || btnLeftHit || btnRightHit) {
        turnScreenOn();
        Serial.println("[ROBOT] Wybudzenie przyciskiem!");
        currentState = STATE_AWAKE;
        stateChangeTimestamp = now;
        playWakeUpAnimation();
        wakeUpTimestamp = millis();
        break;
      }

      if (!isScreenTurnedOff) {
        if (now - stateChangeTimestamp > 5000) {
          // Po 5 sekundach od uśpienia / 2. potrząśnięcia ekranik całkowicie gaśnie i się wyłącza!
          turnScreenOff();
        } else {
          // Przez pierwsze 5 sekund po uśpieniu: animacja spokojnego oddechu i literek "z Z Z" co 750 ms
          if (now - lastSleepAnimTick > 750) {
            lastSleepAnimTick = now;
            sleepAnimPhase = (sleepAnimPhase + 1) % 3;
            drawSleepEyes(sleepAnimPhase);
          }
        }
      }

      // Rozładowywanie baterii w spoczynku (tylko w symulatorze Wokwi przy odłączonym kablu)
      if (isWokwiEnvironment && !isUsbConnected && (now - lastBatteryTick > 6000)) {
        lastBatteryTick = now;
        if (batteryPercent > 0) batteryPercent -= 1.0f;
        if (batteryPercent < 15.0f) {
          turnScreenOn();
          currentState = STATE_LOW_BATTERY_SAD;
          stateChangeTimestamp = now;
        }
      }
      break;

    // --- ROBOT WYBUDZONY ---
    case STATE_AWAKE:
      // Wciśnięcie przycisku OK otwiera MENU GŁÓWNE!
      if (btnOkHit) {
        soundConfirm();
        currentState = STATE_MENU;
        currentMenuIndex = 0;
        drawMenuScreen();
        break;
      }
      // W zwykłym trybie czuwania przyciski LEWO/PRAWO nie zmieniają motywu/kształtu (tylko w Menu!)
      // Zamiast tego robot interaktywnie zerka w lewo lub w prawo:
      if (btnLeftHit) {
        soundNavClick();
        drawEyes(36, -14, 0);
        delay(160);
        drawEyes(36, 0, 0);
      }
      if (btnRightHit) {
        soundNavClick();
        drawEyes(36, 14, 0);
        delay(160);
        drawEyes(36, 0, 0);
      }

      // Rozładowywanie podczas aktywności (tylko w symulatorze Wokwi przy odłączonym kablu)
      if (isWokwiEnvironment && !isUsbConnected && (now - lastBatteryTick > 1500)) {
        lastBatteryTick = now;
        if (batteryPercent > 0) batteryPercent -= 1.0f;
        Serial.printf("[BATERIA] Pozostalo: %.0f%%\n", batteryPercent);

        // Wykrycie niskiego stanu baterii (< 20%)
        if (batteryPercent < 20.0f) {
          Serial.println("\n--> [UWAGA] BATERIA NA WYCZERPANIU! Robot jest zmeczony...");
          currentState = STATE_LOW_BATTERY_SAD;
          stateChangeTimestamp = now;
          drawSadTiredEyes();
          soundSadBattery();
          break;
        }
      }

      // Organiczne rozglądanie się w lewo i prawo oraz mruganie w stanie bezczynności
      handleIdleEyes(now);
      break;

    // --- ROBOT POGŁASKANY (MRUCZENIE I SERDUSZKA) ---
    case STATE_HAPPY_PET: {
      unsigned long cur = millis();
      if (cur < happyPetStartTime) happyPetStartTime = cur;
      unsigned long elapsed = cur - happyPetStartTime;

      if (elapsed > 3300) {
        // Po 3.3 sekundy wróć do normalnej twarzy robota
        currentState = STATE_AWAKE;
        wakeUpTimestamp = cur;
        stateChangeTimestamp = cur;
        drawEyes(36, 0, 0);
        break;
      }

      // Realistyczny, dwufazowy dźwięk mruczenia kota (wdech i wydech: cykl 600 ms)
      if (!isHappySurprised) {
        int purrPhase = elapsed % 600;
        if (purrPhase < 260 && (now - lastPurrTick > 45)) {
          lastPurrTick = now;
          int f = 260 + (purrPhase / 4);
          tone(BUZZER_PIN, f, 28);
        } else if (purrPhase >= 320 && purrPhase < 560 && (now - lastPurrTick > 45)) {
          lastPurrTick = now;
          int f = 320 - ((purrPhase - 320) / 4);
          tone(BUZZER_PIN, f, 28);
        }
      }

      // Kliknięcie OK otwiera menu również stąd
      if (btnOkHit) {
        soundConfirm();
        currentState = STATE_MENU;
        currentMenuIndex = 0;
        drawMenuScreen();
        break;
      }

      // Rysowanie animacji zadowolenia na ekranie
      drawHappyPetEyes(elapsed, isHappySurprised);
      break;
    }

    // --- MENU GŁÓWNE ---
    case STATE_MENU:
      if (btnLeftHit) {
        currentMenuIndex = (currentMenuIndex - 1 + MENU_ITEMS_COUNT) % MENU_ITEMS_COUNT;
        soundNavClick();
        drawMenuScreen();
      }
      if (btnRightHit) {
        currentMenuIndex = (currentMenuIndex + 1) % MENU_ITEMS_COUNT;
        soundNavClick();
        drawMenuScreen();
      }
      if (btnOkHit) {
        soundConfirm();
        if (currentMenuIndex == 0) {
          currentState = STATE_SUB_EYES;
          drawEyesSubMenu();
        } else if (currentMenuIndex == 1) {
          currentState = STATE_SUB_POMODORO;
          drawPomodoroScreen();
        } else if (currentMenuIndex == 2) {
          currentState = STATE_SUB_GAME;
          isGameOver = false;
          gameScore = 0;
          gamePlayerY = 44.0f;
          gamePlayerVy = 0.0f;
          gameObstacleX = 130;
          drawGameScreen();
        } else if (currentMenuIndex == 3) {
          // Powrót do oczek
          currentState = STATE_AWAKE;
          wakeUpTimestamp = now;
          drawEyes(36, 0, 0);
        }
      }
      break;

    // --- PODEKRAN: STYL I MOTYW OCZU ---
    case STATE_SUB_EYES:
      if (btnLeftHit) {
        currentTheme = (currentTheme + 1) % THEME_COUNT;
        soundNavClick();
        drawEyesSubMenu();
      }
      if (btnRightHit) {
        currentShape = (currentShape + 1) % SHAPE_COUNT;
        soundNavClick();
        drawEyesSubMenu();
      }
      if (btnOkHit) {
        soundConfirm();
        currentState = STATE_MENU;
        drawMenuScreen();
      }
      break;

    // --- PODEKRAN: MONITOR PODZESPOŁÓW PC ---
    case STATE_SUB_PC_MONITOR:
      updatePcStats();
      if (now - lastAnimTick > 150) {
        lastAnimTick = now;
        drawPcMonitorScreen();
      }
      if (btnOkHit || btnLeftHit) {
        soundBack();
        currentState = STATE_MENU;
        drawMenuScreen();
      }
      break;
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

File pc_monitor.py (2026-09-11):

#!/usr/bin/env python3
"""
Desk Buddy - PC Hardware Monitor Script
Wysyła w czasie rzeczywistym parametry komputera (CPU, RAM, GPU) do robota przez port szeregowy (USB).
Wymaga: pip install psutil pyserial
"""

import time
import sys

try:
    import psutil
    import serial
    import serial.tools.list_ports
except ImportError:
    print("[!] Zainstaluj wymagane biblioteki: pip install psutil pyserial")
    sys.exit(1)

def find_esp_port():
    ports = serial.tools.list_ports.comports()
    for p in ports:
        if "CP210" in p.description or "CH340" in p.description or "USB" in p.description:
            return p.device
    return ports[0].device if ports else None

def main():
    port = sys.argv[1] if len(sys.argv) > 1 else find_esp_port()
    if not port:
        print("[!] Nie znaleziono podłączonego portu ESP32. Podaj port jako argument, np: python3 pc_monitor.py /dev/ttyUSB0")
        sys.exit(1)

    print(f"[*] Łączenie z Desk Buddy na porcie {port} (115200 baud)...")
    try:
        ser = serial.Serial(port, 115200, timeout=1)
        time.sleep(2)
        print("[+] Połączono! Wysyłanie danych o obciążeniu PC co 1 sekundę. Naciśnij Ctrl+C aby zakończyć.")

        while True:
            cpu = psutil.cpu_percent(interval=0.5)
            ram = psutil.virtual_memory().percent
            # Prosta symulacja/estymacja GPU lub odczyt jeśli dostępny
            gpu = min(100.0, cpu * 1.1 + 5.0)
            temp = 45.0 + (cpu * 0.25)

            cmd = f"pc cpu={cpu:.0f} ram={ram:.0f} gpu={gpu:.0f} temp={temp:.0f}\n"
            ser.write(cmd.encode('utf-8'))
            print(f"\r[-> ROBOT] CPU: {cpu:4.1f}% | RAM: {ram:4.1f}% | GPU: {gpu:4.1f}% | Temp: {temp:4.1f}°C", end="", flush=True)
            time.sleep(1.0)

    except KeyboardInterrupt:
        print("\n[*] Zatrzymano monitor.")
    except Exception as e:
        print(f"\n[!] Błąd połączenia: {e}")

if __name__ == "__main__":
    main()

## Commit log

2026-09-11 Initial commit: ESP32 Robot Desk Pet with capacitive touch, OLED eyes and Wokwi simulation
2026-09-11 feat: Plug & Play hardware auto-detection, capacitive touch auto-calibration, multi-address I2C and comprehensive README wiring guide
2026-09-12 feat: Add 3D printable enclosure, Blender scene, STLs and assembly guide
    [Buzzer.stl, ESP32_Podstawa.stl, MPU6050_Ruch.stl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]
2026-09-12 feat(cad): dodano nowa obudowe Cyber-Capsule Mecha-Kawaii ze szponterami, wizjerem 3D i lapkami
    [kawaii_obudowa_gora_glowa.stl, kawaii_przycisk_lapka.stl, kawaii_przycisk_serce.stl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]
2026-09-12 feat(blender): dodano dedykowany plik robot_mecha_kawaii.blend z widokiem Mecha Kawaii
    [robot_mecha_kawaii.blend, robot_obudowa_klasyczna.blend]
2026-09-12 feat(cad): dodano 3. wersje obudowy Cyber-Titan Dreadnought (ciezki mech bojowy, radiatory, blast-shield)
    [dreadnought_glowa.step, dreadnought_glowa.stl, dreadnought_podstawa.step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]
2026-09-12 feat(cad): wdrozenie ekstremalnej bryly Cyber-Titan Apex (72mm naramienniki, 68mm rogi V-Fin, dysze odrzutowe, gasienice)
    [dreadnought_glowa.step, dreadnought_glowa.stl, dreadnought_podstawa.step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]
2026-09-12 feat(cad): wdrozenie uniwersalnego stelaza Core z lozami elektroniki i beznarzedziowej wymiany obudow Slide-On
    [core_chassis.step, core_chassis.stl, dreadnought_glowa.step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]
2026-09-13 docs: zaktualizowano glowny README.md z kompletna instrukcja flashowania ESP32 i wykazem plikow STL do druku 3D
2026-09-13 feat(cad): wdrozenie 4. stylu obudowy Steam-Titan Nautilus (Industrial Steampunk/Dieselpunk z kominami, manometrami i kolem zaworu)
    [dieselpunk_glowa.step, dieselpunk_glowa.stl, dieselpunk_podstawa.step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]
2026-09-13 feat(cad): upgrade Steam-Titan Nautilus do wersji ULTRA i ponowna weryfikacja matematyczna systemu Quick-Swap
    [dieselpunk_glowa.step, dieselpunk_glowa.stl, dieselpunk_podstawa.step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]
2026-09-13 feat(cad): przeprojektowano od zera stelaż elektroniki (Universal Core Chassis v2.0) pod precyzyjne wymiary podzespołów
    [core_chassis.step, core_chassis.stl, dieselpunk_glowa.step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]
2026-09-13 fix(cad): completely free MPU-6050 bay from chassis walls and align buzzer cup
    [core_chassis.step, core_chassis.stl, robot_core_chassis.FCStd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]
2026-09-13 fix(cad): calkowicie odblokowano szyne ESP32, powiekszono otwory przyciskow i ulepszono montaz OLED z weryfikacja pasowania 0mm³
    [core_chassis.step, core_chassis.stl, dieselpunk_glowa.step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]
